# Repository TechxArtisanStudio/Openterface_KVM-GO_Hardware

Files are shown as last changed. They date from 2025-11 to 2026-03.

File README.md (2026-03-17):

# Welcome to Openterface_KVM-GO_Hardware
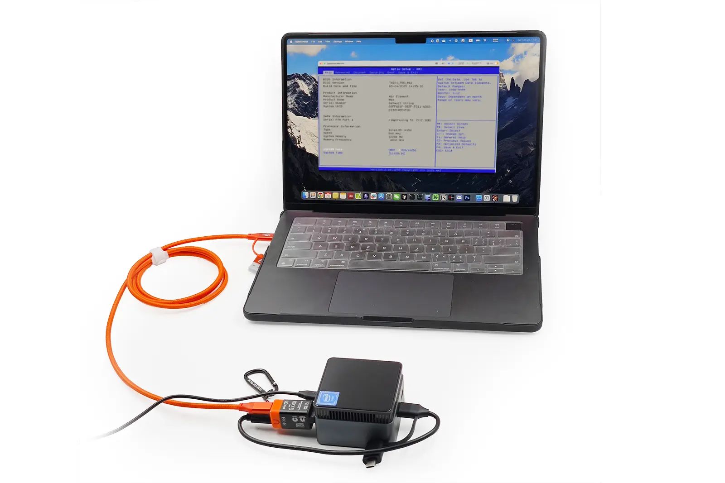
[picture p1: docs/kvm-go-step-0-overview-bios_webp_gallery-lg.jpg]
use-case-pc-angled-view


## Overview

The [Openterface KVM-GO](https://openterface.com/product/kvm-go/) is a compact and portable open-source KVM-over-USB gadget designed to provide convenient access to headless devices. It allows users to use their laptop, tablet, or smartphone to display and control a target machine through a direct USB connection.

The KVM-GO series includes three hardware variants, designed for different video interfaces:

- KVM-GO HDMI  
- KVM-GO DP  
- KVM-GO VGA  

Each variant integrates a video capture interface and keyboard/mouse emulation into a single compact device. By connecting the device to the target machine’s video output and USB port, users can view the screen and control the system from a host device without requiring network connectivity.

This solution is particularly useful for developers, IT professionals, and hardware enthusiasts who frequently work with servers, embedded systems, or other headless devices.

## Hardware Features

The Openterface KVM-GO PCB board comes with a variety of features designed to provide a seamless and efficient user experience:

- Compact Design: Small and portable form factor suitable for mobile troubleshooting setups.  
- Multiple Video Variants: Available in HDMI, DP, and VGA versions to support different target devices.  
- Direct Plug-in Video Interface: Built-in connector allows direct connection to the target system.  
- USB Connectivity: Simulates keyboard and mouse inputs through a USB connection.  
- Open Source: Fully open-source hardware and software, allowing community-driven development and customization.  
- High Compatibility: Supports a wide range of devices and operating systems.  
- Easy Setup: Plug-and-play functionality with minimal configuration required.  
- [Community Support](https://openterface.com/about/community/): Backed by an active open-source community.
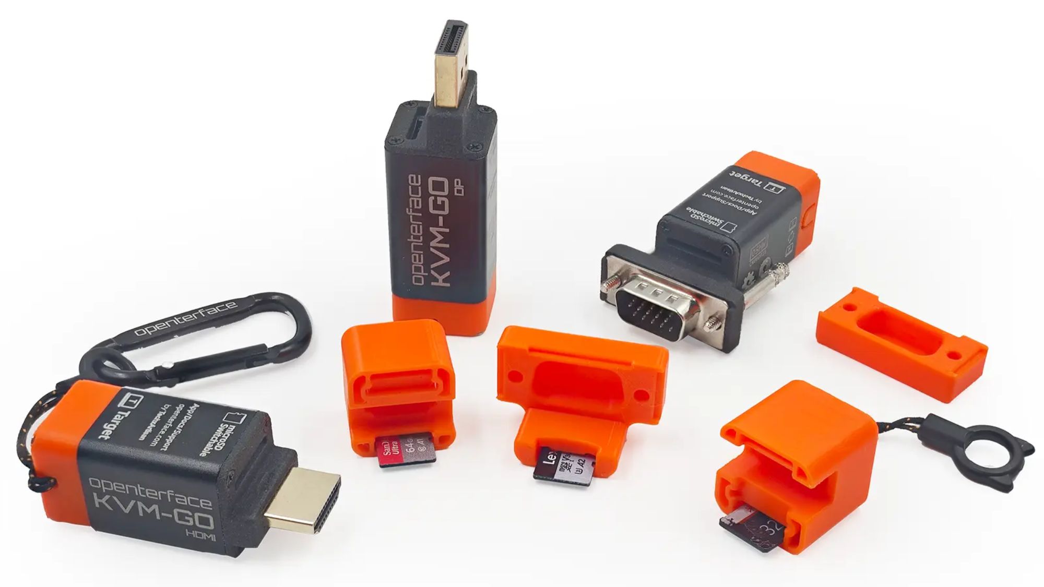
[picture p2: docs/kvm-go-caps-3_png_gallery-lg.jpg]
KVM-GO series
  

## Firmware

KVM-GO works with [Openterface_KM](https://github.com/TechxArtisanStudio/Openterface_KM), the keyboard and mouse emulation firmware used for target-side HID control in the Openterface KVM ecosystem.

## Software

To use the KVM-GO device, the host device must install an Openterface host application.

Supported platforms include:

- [Windows](https://github.com/TechxArtisanStudio/Openterface_QT)
- [Mac](https://github.com/TechxArtisanStudio/Openterface_MacOS)
- [Linux](https://github.com/TechxArtisanStudio/Openterface_QT)  
- [Android](https://github.com/TechxArtisanStudio/Openterface_Android)
- iPadOS  
- [Web browser applications](https://openterface-viewer.pages.dev/)  

The host application allows users to view the captured video stream and control the target device using keyboard and mouse input.

No software installation is required on the target device. Simply connect a device with a video output and a USB port for keyboard and mouse control.

## PCB Design
_cgi-bin_mmwebwx-bin_webwxgetmsgimg__ MsgID=7964427320763733275 skey=@crypt_1f07134c_f258b5d86cb3b41255d6e1a63a1030d6 mmweb_appid=wx_webfilehelper

## license

- Hardware is released under CERN Open Hardware Licence Version 2 - Strongly Reciprocal  
- Its softwares are released under GNU AFFERO GENERAL PUBLIC LICENSE Version 3  
- Documentation is released under [CC BY-SA 4.0](https://creativecommons.org/licenses/by-sa/4.0/legalcode)

## Get Involved

Interested in contributing to the project? We welcome community involvement and contributions. For more information about getting involved, please visit our community pages or contact us directly.

KVM-GO-bundle-hook-bag

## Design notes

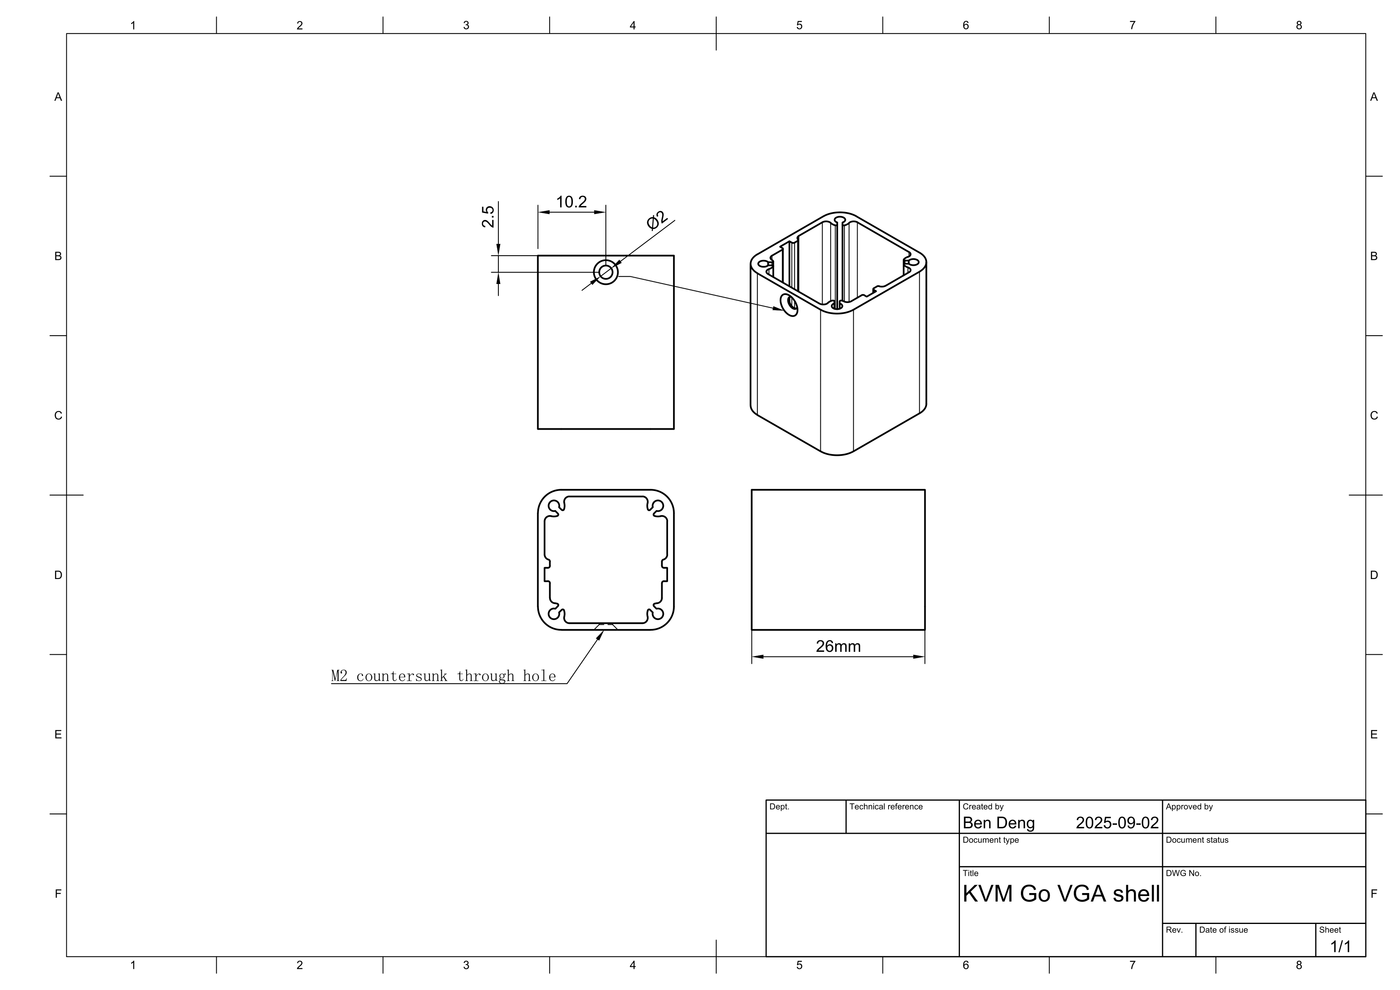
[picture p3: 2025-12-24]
models/VGA/KVM_Go_VGA.png

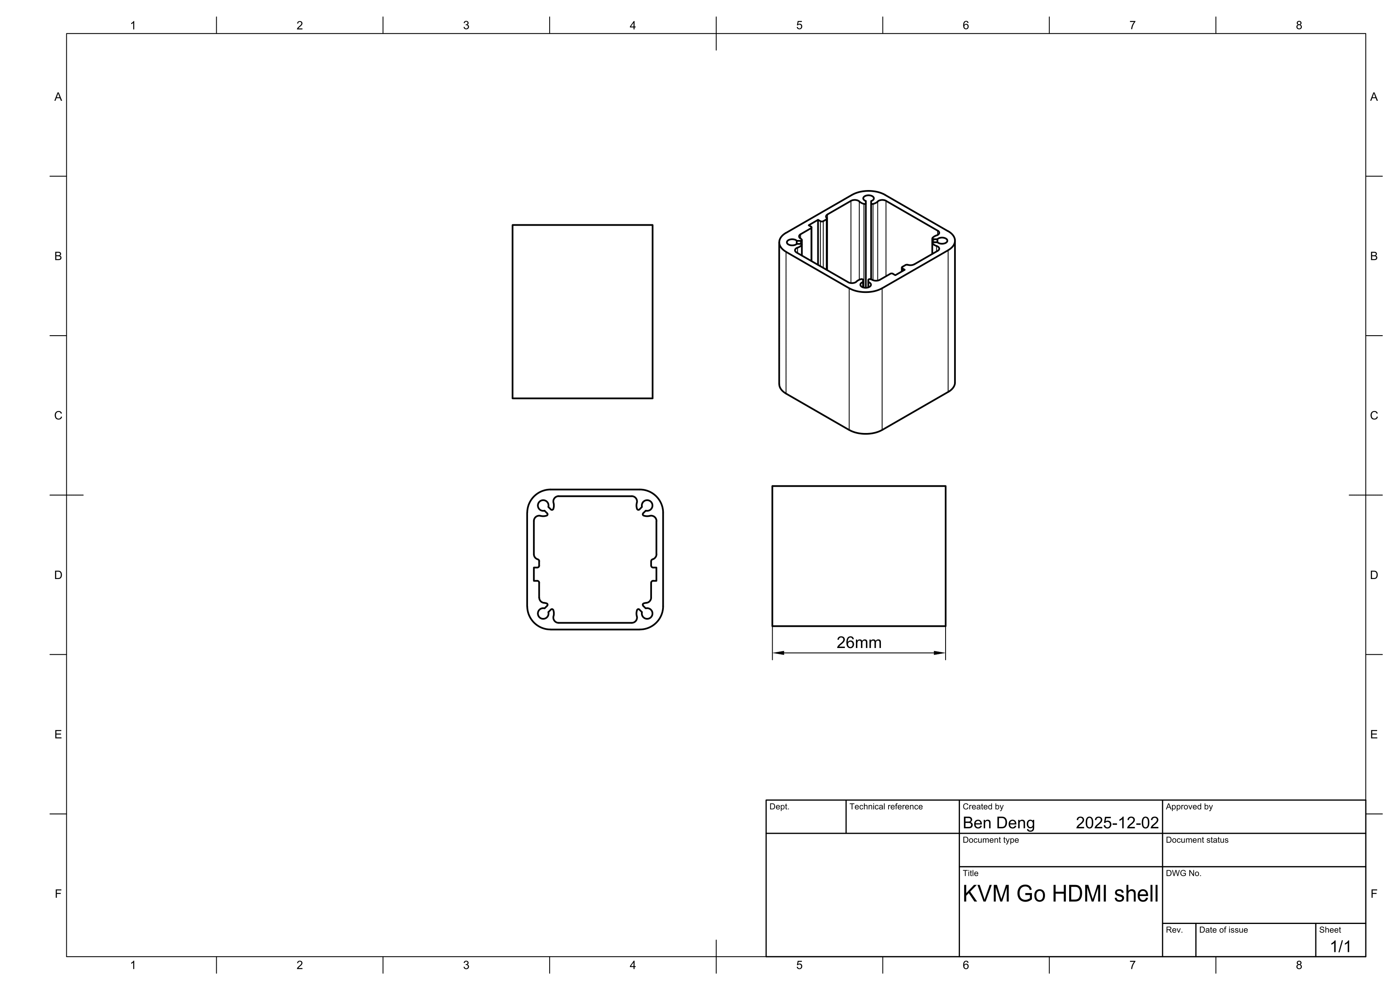
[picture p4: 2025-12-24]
models/HDMI/KVM_Go_HDMI.png

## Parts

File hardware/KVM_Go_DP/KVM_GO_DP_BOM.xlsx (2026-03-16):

No. | Quantity | Comment | Designator | Footprint | Value | Manufacturer Part | Manufacturer | Supplier Part | Supplier
1 | 7 | 10uF | C1,C2,C3,C7,C17,C30,C35 | C0402 | 10uF | HGC0402R5106M100NTEJ | Chinocera(华瓷) | C7472949 | LCSC
2 | 27 | 100nF | C4,C5,C6,C8,C10,C13,C14,C18,C19,C20,C21,C22,C23,C24,C25,C28,C29,C31,C32,C33,C34,C36,C37,C38,C39,C40,C41 | C0402 | 100nF | CL05B104KO5NNNC | SAMSUNG(三星) | C1525 | LCSC
3 | 4 | 100nF | C9,C12,C26,C27 | C0201 | 100nF | CGA0201X5R104K100ET | HRE(芯声) | C6119757 | LCSC
4 | 2 | 18pF | C11,C15 | C0402 | 18pF | CC0402FRNPO9BN180 | YAGEO(国巨) | C541431 | LCSC
5 | 1 | 1uF | C16 | C0402 | 1uF | CL05A105KA5NQNC | SAMSUNG(三星) | C52923 | LCSC
6 | 1 | 10uF | C42 | C0603 | 10uF | CGA0603X5R106K100JT | HRE(芯声) | C6119842 | LCSC
7 | 1 | DISPLAYPORT_公_夹板 | CN1 | DISPLAYPORT_公_夹板
8 | 1 | PRTR5V0U2X | D11 | SOT-143-4_L2.9-W1.3-P1.92-LS2.4-BL |  | PRTR5V0U2X | TECH PUBLIC(台舟) | C2827688 | LCSC
9 | 2 | RClamp0524PATCT | D12,D13 | SLP2510P8_L2.5-W1.0-P0.50-BL |  | RClamp0524PATCT | SEMTECH | C40960 | LCSC
10 | 4 | MPZ1608S600ATDH5 | FB1,FB2,FB3,FB4 | L0603 |  | MPZ1608S600ATDH5 | TDK | C307775 | LCSC
11 | 2 | 5AKL3-8840-103-W0 | H1,H2 | HDR-TH_3P-P2.00-V-M |  | 5AKL3-8840-103-W0 | SAMZO(三佐) | C29780895 | LCSC
12 | 2 | 2.2uH | L1,L2 | IND-SMD_L2.0-W1.6-B | 2.2uH | FWP201610P-2R2ML | cjiang(长江微电) | C5179461 | LCSC
13 | 1 | 2.2uH | L4 | L0603 | 2.2uH | CMH160808B2R2MT | FH(风华) | C394950 | LCSC
14 | 1 | 4.7kΩ | R1 | R0402 | 4.7kΩ | 0402WGF4701TCE | UNI-ROYAL(厚声) | C25900 | LCSC
15 | 1 | 41.2kΩ | R2 | R0402 | 41.2kΩ | FRC0402F4122TS | FOJAN(富捷) | C2998053 | LCSC
16 | 4 | 1MΩ | R3,R4,R9,R10 | R0402 | 1MΩ | 0402WGF1004TCE | UNI-ROYAL(厚声) | C26083 | LCSC
17 | 2 | 150kΩ | R5,R19 | R0402 | 150kΩ | FRC0402F1503TS | FOJAN(富捷) | C2909320 | LCSC
18 | 4 | 10kΩ | R6,R7,R14,R22 | R0402 | 10kΩ | 0402WGF1002TCE | UNI-ROYAL(厚声) | C25744 | LCSC
19 | 1 | 220kΩ | R8 | R0402 | 220kΩ | 0402WGF2203TCE | UNI-ROYAL(厚声) | C25767 | LCSC
20 | 1 | 200Ω | R11 | R0402 | 200Ω | 0402WGF2000TCE | UNI-ROYAL(厚声) | C25087 | LCSC
21 | 1 | 47kΩ | R12 | R0402 | 47kΩ | 0402WGF4702TCE | UNI-ROYAL(厚声) | C25792 | LCSC
22 | 1 | 10.5kΩ | R13 | R0402 | 10.5kΩ | 0402WGF1052TCE | UNI-ROYAL(厚声) | C25850 | LCSC
23 | 1 | 22kΩ | R15 | R0402 | 22kΩ | 0402WGF2202TCE | UNI-ROYAL(厚声) | C25768 | LCSC
24 | 1 | 1.6kΩ | R16 | R0402 | 1.6kΩ | 0402WGF1601TCE | UNI-ROYAL(厚声) | C4908 | LCSC
25 | 1 | 0Ω | R17 | R0402 | 0Ω | 0402WGF0000TCE | UNI-ROYAL(厚声) | C17168 | LCSC
26 | 1 | 680kΩ | R18 | R0402 | 680kΩ | RC0402FR-07680KL | YAGEO(国巨) | C163456 | LCSC
27 | 2 | 1kΩ | R20,R21 | R0402 | 1kΩ | 0402WGF1001TCE | UNI-ROYAL(厚声) | C11702 | LCSC
28 | 1 | 124kΩ | R23 | R0402 | 124kΩ | FRC0402F1243TS | FOJAN(富捷) | C2933070 | LCSC
29 | 1 | IT6563FN | U2 | QFN-56_L7.0-W7.0-P0.40-BL-EP5.2
30 | 1 | MS2130S | U3 | QFN-64_L9.0-W9.0-P0.50-BL-EP4.8
31 | 2 | BLM18PG121SN1D | U5,U7 | L0603 |  | BLM18PG121SN1D | muRata(村田) | C14709 | LCSC
32 | 1 | TPRT9193-25GB | U8 | SOT-23-5_L2.9-W1.6-P0.95-LS2.8-BL |  | TPRT9193-25GB | TECH PUBLIC(台舟) | C2827655 | LCSC
33 | 1 | W25Q16JVUXIQ | U9 | USON-8_L3.0-W2.0-P0.50-BL-EP |  | W25Q16JVUXIQ | Winbond(华邦) | C2843335 | LCSC
34 | 1 | CH213K | U10 | SOT-23-3_L2.9-W1.6-P1.90-LS2.8-BR |  | CH213K | WCH(南京沁恒) | C5456874 | LCSC
35 | 1 | VL162 | U11 | MQFN-28_L4.5-W3.5-P0.40-BL-EP |  | VL162 | VIA Labs(威锋电子) | C19270896 | LCSC
36 | 3 | TLV62569DBVR | U29,U30,U31 | SOT-23-5_L3.0-W1.7-P0.95-LS2.8-BR |  | TLV62569DBVR | TI(德州仪器) | C141836 | LCSC
37 | 1 | 918-418K2029F30000 | USB1 | USB-C-SMD_918-418K2029F30000 |  | 918-418K2029F30000 | 精拓金 | C709039 | LCSC
38 | 1 | 27MHz | X1 | CRYSTAL-SMD_4P-L3.2-W2.5-BL-1 | 27MHz | X322527MSB4SI | YXC(扬兴晶振) | C9008 | LCSC
39 | 1 | 24MHz | X2 | CRYSTAL-SMD_4P-L3.2-W2.5-BL | 24MHz | X322524MOB4SI | YXC(扬兴晶振) | C70590 | LCSC

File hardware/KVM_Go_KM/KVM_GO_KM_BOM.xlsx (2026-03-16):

No. | Quantity | Comment | Designator | Footprint | Value | Manufacturer Part | Manufacturer | Supplier Part | Supplier
1 | 3 | 1uF | C1,C2,C3 | C0402 | 1uF | CL05A105KA5NQNC | SAMSUNG(三星) | C52923 | LCSC
2 | 2 | 12pF | C4,C5 | C0402 | 12pF | GCM1555C1H120FA16D | muRata(村田) | C393682 | LCSC
3 | 1 | 22nF | C6 | C0402 | 22nF | CL05B223KB5NNNC | SAMSUNG(三星) | C337699 | LCSC
4 | 14 | 100nF | C7,C8,C9,C10,C12,C13,C14,C15,C16,C17,C18,C19,C20,C21 | C0402 | 100nF | CL05B104KO5NNNC | SAMSUNG(三星) | C1525 | LCSC
5 | 1 | 10uF | C11 | C0402 | 10uF | HGC0402R5106M100NTEJ | Chinocera(华瓷) | C7472949 | LCSC
6 | 1 | TF PUSH | CARD1 | TF-SMD_TF-PUSH |  | TF PUSH | SHOU HAN(首韩) | C393941 | LCSC
7 | 2 | 5AKL3-8840-103-W0 | H1,H2 | HDR-TH_3P-P2.00-V-M_5 |  | 5AKL3-8840-103-W0 | SAMZO(三佐) | C29780895 | LCSC
8 | 2 | SL2.1s | HUB1,HUB2 | SSOP-16_L4.6-W2.6-P0.53-LS4.0-BL |  | SL2.1s | CoreChips(和芯润德) | C2684433 | LCSC
9 | 1 | 1.5nH | L1 | L0402 | 1.5nH | LQG15HS1N5S02D | muRata(村田) | C77106 | LCSC
10 | 1 | 2nH | L2 | L0402 | 2nH | LQG15HS2N0S02D | muRata(村田) | C18216 | LCSC
11 | 1 | FM-3510RGBA-SG | LED1 | LED-SMD_FM-3510RGBA-SG |  | FM-3510RGBA-SG | 国星光电 | C727903 | LCSC
12 | 1 | 0Ω | R1 | R0402 | 0Ω | 0402WGF0000TCE | UNI-ROYAL(厚声) | C17168 | LCSC
13 | 3 | 10kΩ | R2,R4,R5 | R0402 | 10kΩ | 0402WGF1002TCE | UNI-ROYAL(厚声) | C25744 | LCSC
14 | 2 | 5.1kΩ | R3,R6 | R0402 | 5.1kΩ | 0402WGF5101TCE | UNI-ROYAL(厚声) | C25905 | LCSC
15 | 2 | 4.7kΩ | R8,R9 | R0402 | 4.7kΩ | 0402WGF4701TCE | UNI-ROYAL(厚声) | C25900 | LCSC
16 | 1 | 10kΩ | R10 | R0201 | 10kΩ | 0201WMF1002TEE | UNI-ROYAL(厚声) | C473048 | LCSC
17 | 1 | TS-1133-C-A | SW1 | SW-SMD_TS-1133-C-A |  | TS-1133-C-A | XKB Connectivity(中国星坤) | C561509 | LCSC
18 | 1 | CH32V208GBU6 | U1 | QFN-28_L4.0-W4.0-P0.40-BL-EP2.8 |  | CH32V208GBU6 | WCH(南京沁恒) | C7434833 | LCSC
19 | 1 | ADWH002 | U2 | ANT-SMD_L5.0-W2.0_HM5B |  | ADWH002 | MyAntenna(摩天射频) | C22467691 | LCSC
20 | 1 | RT9193-33GB | U3 | SOT-23-5_L3.0-W1.7-P0.95-LS2.8-BL |  | RT9193-33GB | RICHTEK(立锜) | C15651 | LCSC
21 | 1 | GL823K-HCY04 | U4 | SSOP-16_L4.9-W3.9-P0.64-LS6.0-BL |  | GL823K-HCY04 | GENESYS(创惟) | C284879 | LCSC
22 | 1 | FSUSB42MUX | U5 | MSOP-10_L3.0-W3.0-P0.50-LS5.0-BL |  | FSUSB42MUX | onsemi(安森美) | C11355 | LCSC
23 | 1 | SY6280AAC | U6 | SOT-23-5_L3.0-W1.7-P0.95-LS2.8-BL |  | SY6280AAC | silergy(矽力杰) | C55136 | LCSC
24 | 1 | CH213K | U7 | SOT-23-3_L2.9-W1.6-P1.90-LS2.8-BR |  | CH213K | WCH(南京沁恒) | C5456874 | LCSC
25 | 1 | DS18B20U(UMW) | U8 | MSOP-8_L3.0-W3.0-P0.65-LS4.9-BL |  | DS18B20U(UMW) | UMW(友台半导体) | C695836 | LCSC
26 | 1 | TYPEC-304-ACP16 | USB1 | USB-C-SMD_TYPE-C-16P-1 |  | TYPEC-304-ACP16 | XUNPU(讯普) | C2982555 | LCSC
27 | 1 | 32.768kHz | X1 | CRYSTAL-SMD_2P-L2.0-W1.2 | 32.768kHz | XKHEL89CGI-112YLC-32.768K | YXC(扬兴晶振) | C7500573 | LCSC
28 | 1 | 32MHz | X2 | CRYSTAL-SMD_4P-L3.2-W2.5-BL | 32MHz | X322532MOB4SI | YXC(扬兴晶振) | C9009 | LCSC
29 | 2 | 12MHz | X3,X4 | CRYSTAL-SMD_4P-L2.5-W2.0-BL-A | 12MHz | 2TJ412000HYGBC | JYJE(晶友嘉) | C2149204 | LCSC

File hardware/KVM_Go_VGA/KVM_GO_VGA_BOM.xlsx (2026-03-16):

No. | Quantity | Comment | Designator | Footprint | Value | Manufacturer Part | Manufacturer | Supplier Part | Supplier
1 | 3 | 47nF | C2,C3,C4 | C0402 | 47nF | CC0402KRX7R9BB473 | YAGEO(国巨) | C272875 | LCSC
2 | 10 | 100nF | C5,C43,C45,C76,C77,C80,C83,C85,C87,C93 | C0402 | 100nF | CL05B104KO5NNNC | SAMSUNG(三星) | C1525 | LCSC
3 | 2 | 22pF | C41,C42 | C0402 | 22pF | 0402CG220J500NT | FH(风华) | C1555 | LCSC
4 | 12 | 10uF | C56,C69,C72,C74,C75,C78,C79,C88,C89,C90,C91,C92 | C0402 | 10uF | HGC0402R5106M100NTEJ | Chinocera(华瓷) | C7472949 | LCSC
5 | 3 | 4.7uF | C60,C61,C66 | C0402 | 4.7uF | CL05A475KP5NRNC | SAMSUNG(三星) | C368809 | LCSC
6 | 2 | 10uF | C81,C82 | C0603 | 10uF | CGA0603X5R106K100JT | HRE(芯声) | C6119842 | LCSC
7 | 1 | PRTR5V0U2X | D11 | SOT-143-4_L2.9-W1.3-P1.92-LS2.4-BL |  | PRTR5V0U2X | TECH PUBLIC(台舟) | C2827688 | LCSC
8 | 1 | RClamp0524PATCT | D14 | SLP2510P8_L2.5-W1.0-P0.50-BL |  | RClamp0524PATCT | SEMTECH | C40960 | LCSC
9 | 2 | 5AKL3-8840-103-W0 | H1,H2 | HDR-TH_3P-P2.00-V-M_5 |  | 5AKL3-8840-103-W0 | SAMZO(三佐) | C29780895 | LCSC
10 | 3 | 2.2uH | L6,L7,L8 | IND-SMD_L2.0-W1.6-B | 2.2uH | FWP201610P-2R2ML | cjiang(长江微电) | C5179461 | LCSC
11 | 4 | 4.7kΩ | R1,R6,R7,R9 | R0402 | 4.7kΩ | 0402WGF4701TCE | UNI-ROYAL(厚声) | C25900 | LCSC
12 | 3 | 1kΩ | R2,R40,R45 | R0402 | 1kΩ | 0402WGF1001TCE | UNI-ROYAL(厚声) | C11702 | LCSC
13 | 2 | 1MΩ | R3,R4 | R0402 | 1MΩ | 0402WGF1004TCE | UNI-ROYAL(厚声) | C26083 | LCSC
14 | 2 | 5.1kΩ | R11,R46 | R0402 | 5.1kΩ | 0402WGF5101TCE | UNI-ROYAL(厚声) | C25905 | LCSC
15 | 3 | 75Ω | R14,R18,R19 | R0402 | 75Ω | 0402WGF750JTCE | UNI-ROYAL(厚声) | C25133 | LCSC
16 | 1 | NC | R32 | R0402 | NC | 0402WGF0000TCE | UNI-ROYAL(厚声) |  | LCSC
17 | 1 | 680kΩ | R57 | R0402 | 680kΩ | RC0402FR-07680KL | YAGEO(国巨) | C163456 | LCSC
18 | 4 | 150kΩ | R58,R59,R60,R61 | R0402 | 150kΩ | FRC0402F1503TS | FOJAN(富捷) | C2909320 | LCSC
19 | 1 | 300kΩ | R62 | R0402 | 300kΩ | 0402WGF3003TCE | UNI-ROYAL(厚声) | C25774 | LCSC
20 | 2 | 100Ω | R63,R64 | R0402 | 100Ω | 0402WGF1000TCE | UNI-ROYAL(厚声) | C25076 | LCSC
21 | 1 | CH213K | U1 | SOT-23-3_L2.9-W1.6-P1.90-LS2.8-BR |  | CH213K |  | C5456874 | LCSC
22 | 1 | MS2109S | U4 | QFN-48_L7.0-W7.0-P0.50-TL-EP4.1
23 | 3 | BLM18PG121SN1D | U17,U30,U31 | L0603 |  | BLM18PG121SN1D | muRata(村田) | C14709 | LCSC
24 | 1 | MS9288C | U23 | QFN-48_L6.0-W6.0-P0.40-TL-EP4.2 |  | MS9288C | Macrosilicon(宏晶微) | C2914316 | LCSC
25 | 1 | AT24C16M5/TR | U26 | SOT-23-5_L2.9-W1.6-P0.95-LS2.8-BR |  | AT24C16M5/TR | HGSEMI(华冠) | C7432356 | LCSC
26 | 3 | TLV62569DBVR | U27,U28,U29 | SOT-23-5_L3.0-W1.7-P0.95-LS2.8-BR |  | TLV62569DBVR | TI(德州仪器) | C141836 | LCSC
27 | 1 | 918-418K2029F30000 | USB5 | USB-C-SMD_918-418K2029F30000 |  | 918-418K2029F30000 | 精拓金 |  | LCSC
28 | 1 | VGA15P | VGA1 | 夹板vga
29 | 1 | 24MHz | X1 | CRYSTAL-SMD_4P-L3.2-W2.5-BL | 24MHz | X322524MOB4SI | YXC(扬兴晶振) | C70590 | LCSC
30 | 1 | 24.576MHz | X3 | CRYSTAL-SMD_4P-L2.5-W2.0-BL | 24.576MHz | SX2B24.576F1010F30 | SCTF(星通时频) | C7301978 | LCSC

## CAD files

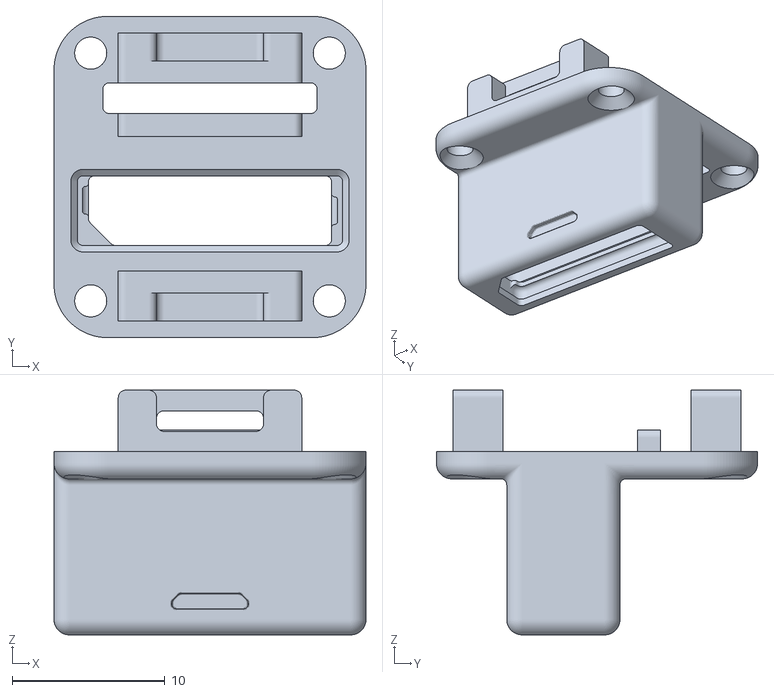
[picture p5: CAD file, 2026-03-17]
models/DP/DP_Cap.stl
20.4 x 21.0 x 16.0

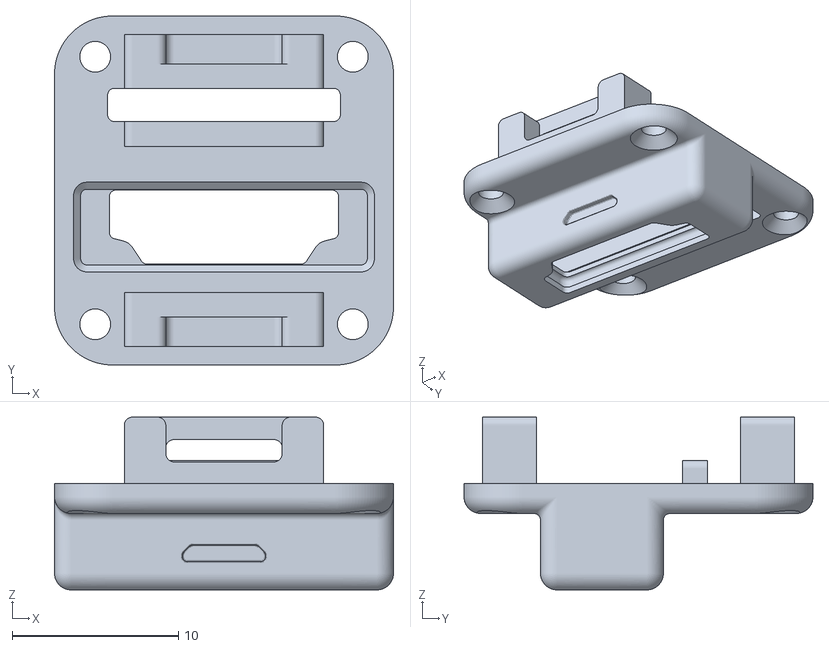
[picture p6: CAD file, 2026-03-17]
models/HDMI/HDMI_Cap.stl
20.4 x 21.0 x 10.4

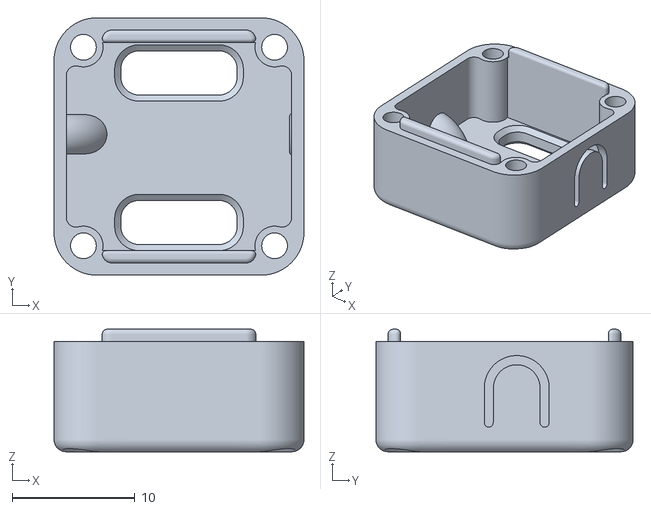
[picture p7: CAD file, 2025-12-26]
models/TypeC_Cap/TypeC_Cap_RGB.stl
20.4 x 21.0 x 10.0

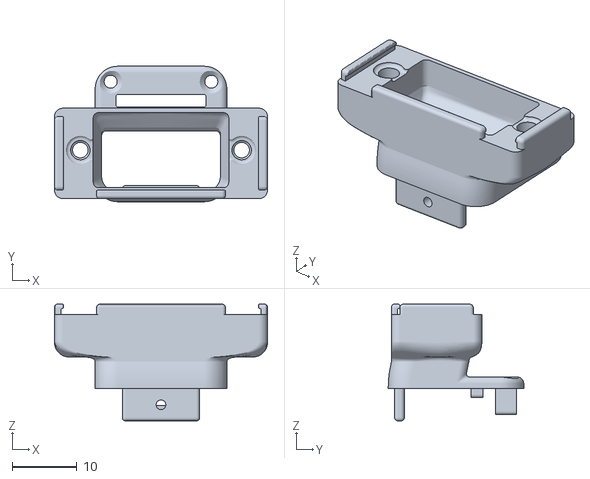
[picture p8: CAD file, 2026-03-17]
models/VGA/VGA_Cap.stl
33.0 x 21.0 x 18.1

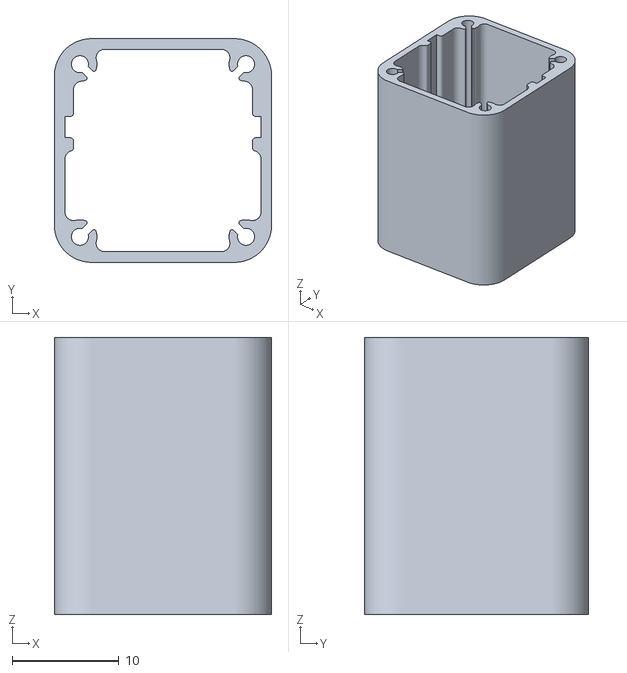
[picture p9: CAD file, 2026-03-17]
models/DP/DP_aluminum_shell.stl
20.4 x 21.0 x 26.0

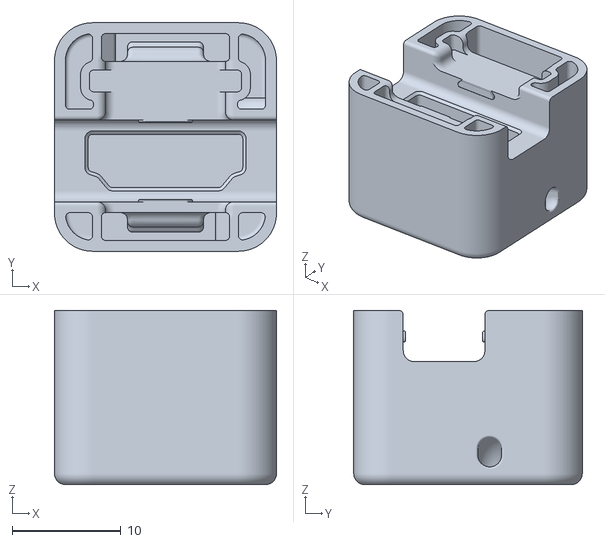
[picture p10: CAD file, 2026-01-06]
models/HDMI/KVM_Go_HDMICaps_WithSDCardSlot and key hole.stl
20.4 x 21.0 x 16.0

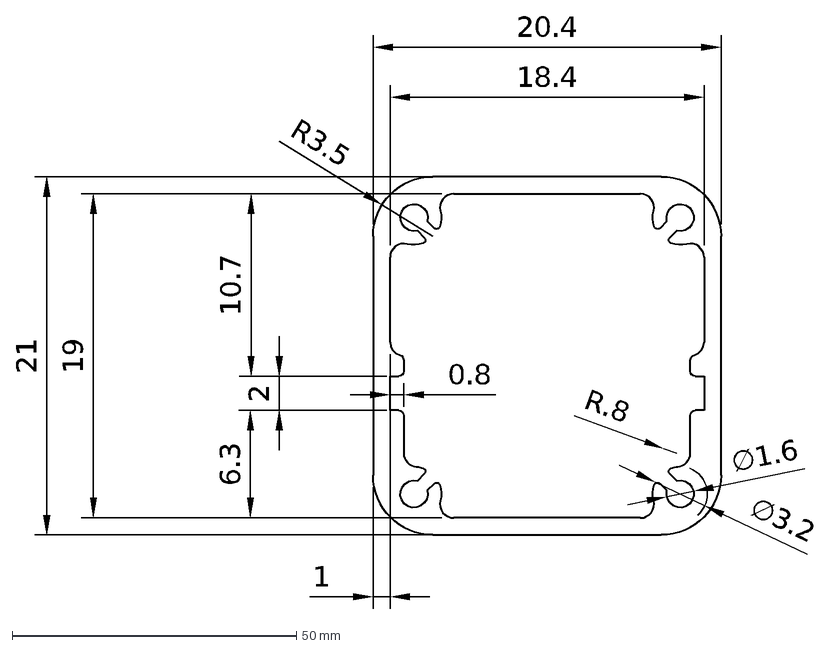
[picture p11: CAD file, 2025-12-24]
models/TypeC_Cap/KVM_Go_shell.dxf
21
20.4
R3.5
1
18.4
19
0.8
6.3
10.7
2
R.8
∅1.6
∅3.2

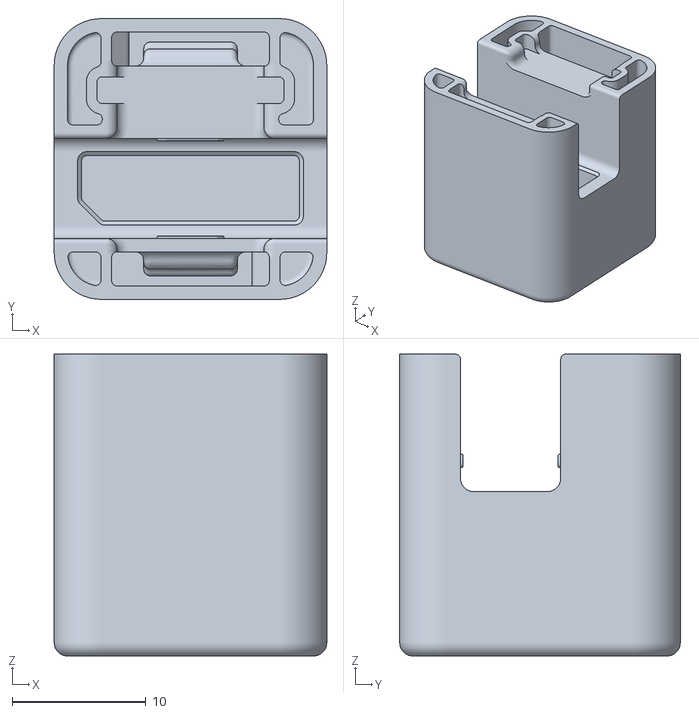
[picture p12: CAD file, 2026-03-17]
models/DP/KVM_Go_DPCaps_WithSDCardSlot.stl
20.4 x 21.0 x 22.6

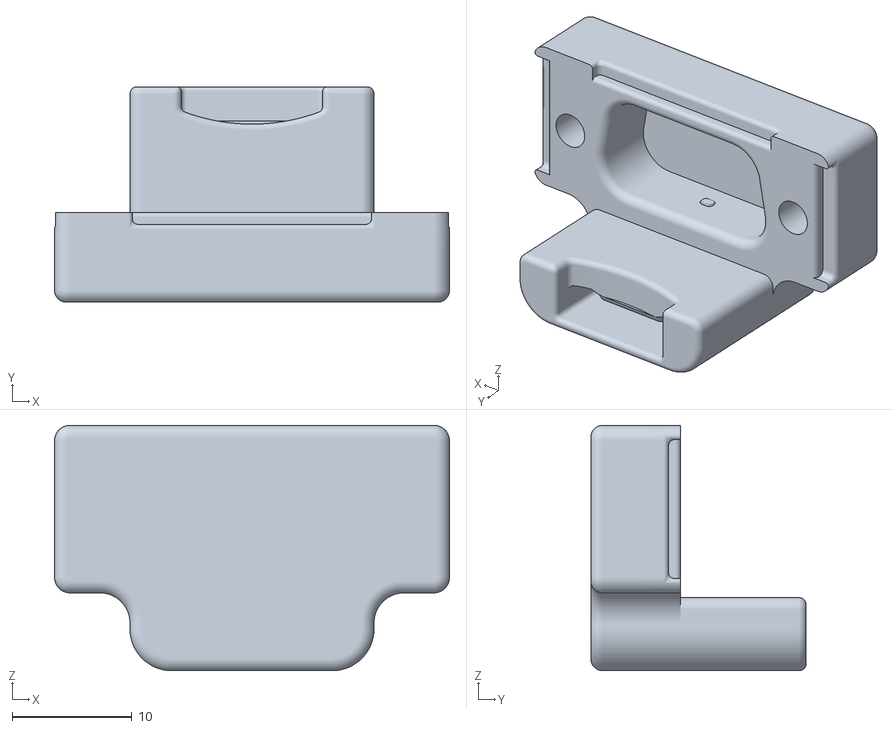
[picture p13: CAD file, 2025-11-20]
models/VGA/KVM_Go_VGACaps_WithSDCardSlot.stl
33.0 x 18.0 x 20.5

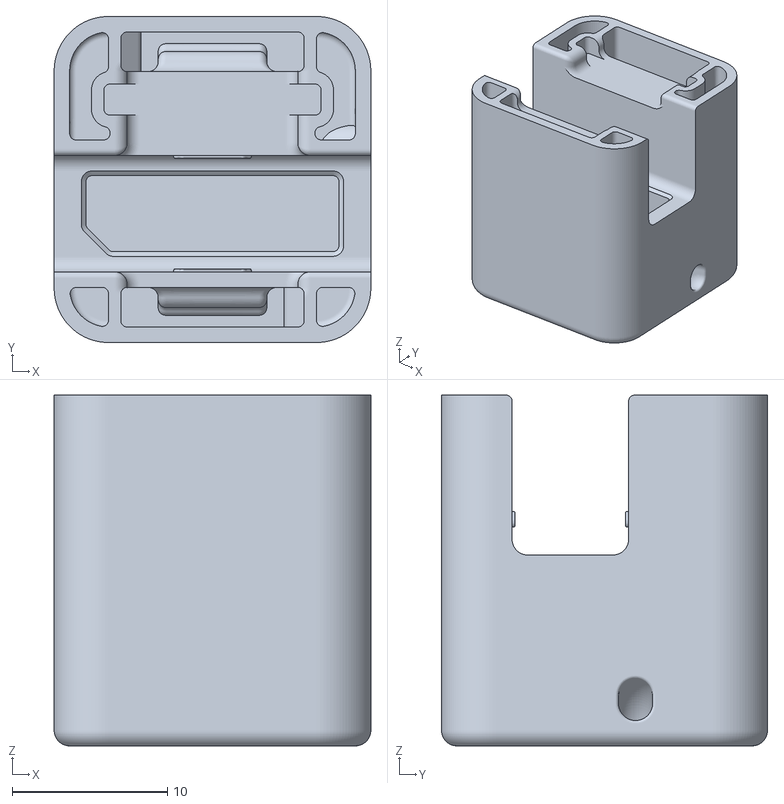
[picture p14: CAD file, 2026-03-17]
models/DP/KVM_Go_DPCaps_WithSDCardSlot and key hole.stl
20.4 x 21.0 x 22.6

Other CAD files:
hardware/KVM_Go_HDMI/KVM_GO_HDMI.step
hardware/KVM_Go_VGA/KVM_GO_VGA.step
models/VGA/VGA_aluminum_shell.stl
models/HDMI/KVM_Go_HDMICaps_WithSDCardSlot.stl
models/HDMI/HDM_aluminum_shell.stl
models/VGA/KVM_Go_VGACaps_WithSDCardSlot and key hole.stl

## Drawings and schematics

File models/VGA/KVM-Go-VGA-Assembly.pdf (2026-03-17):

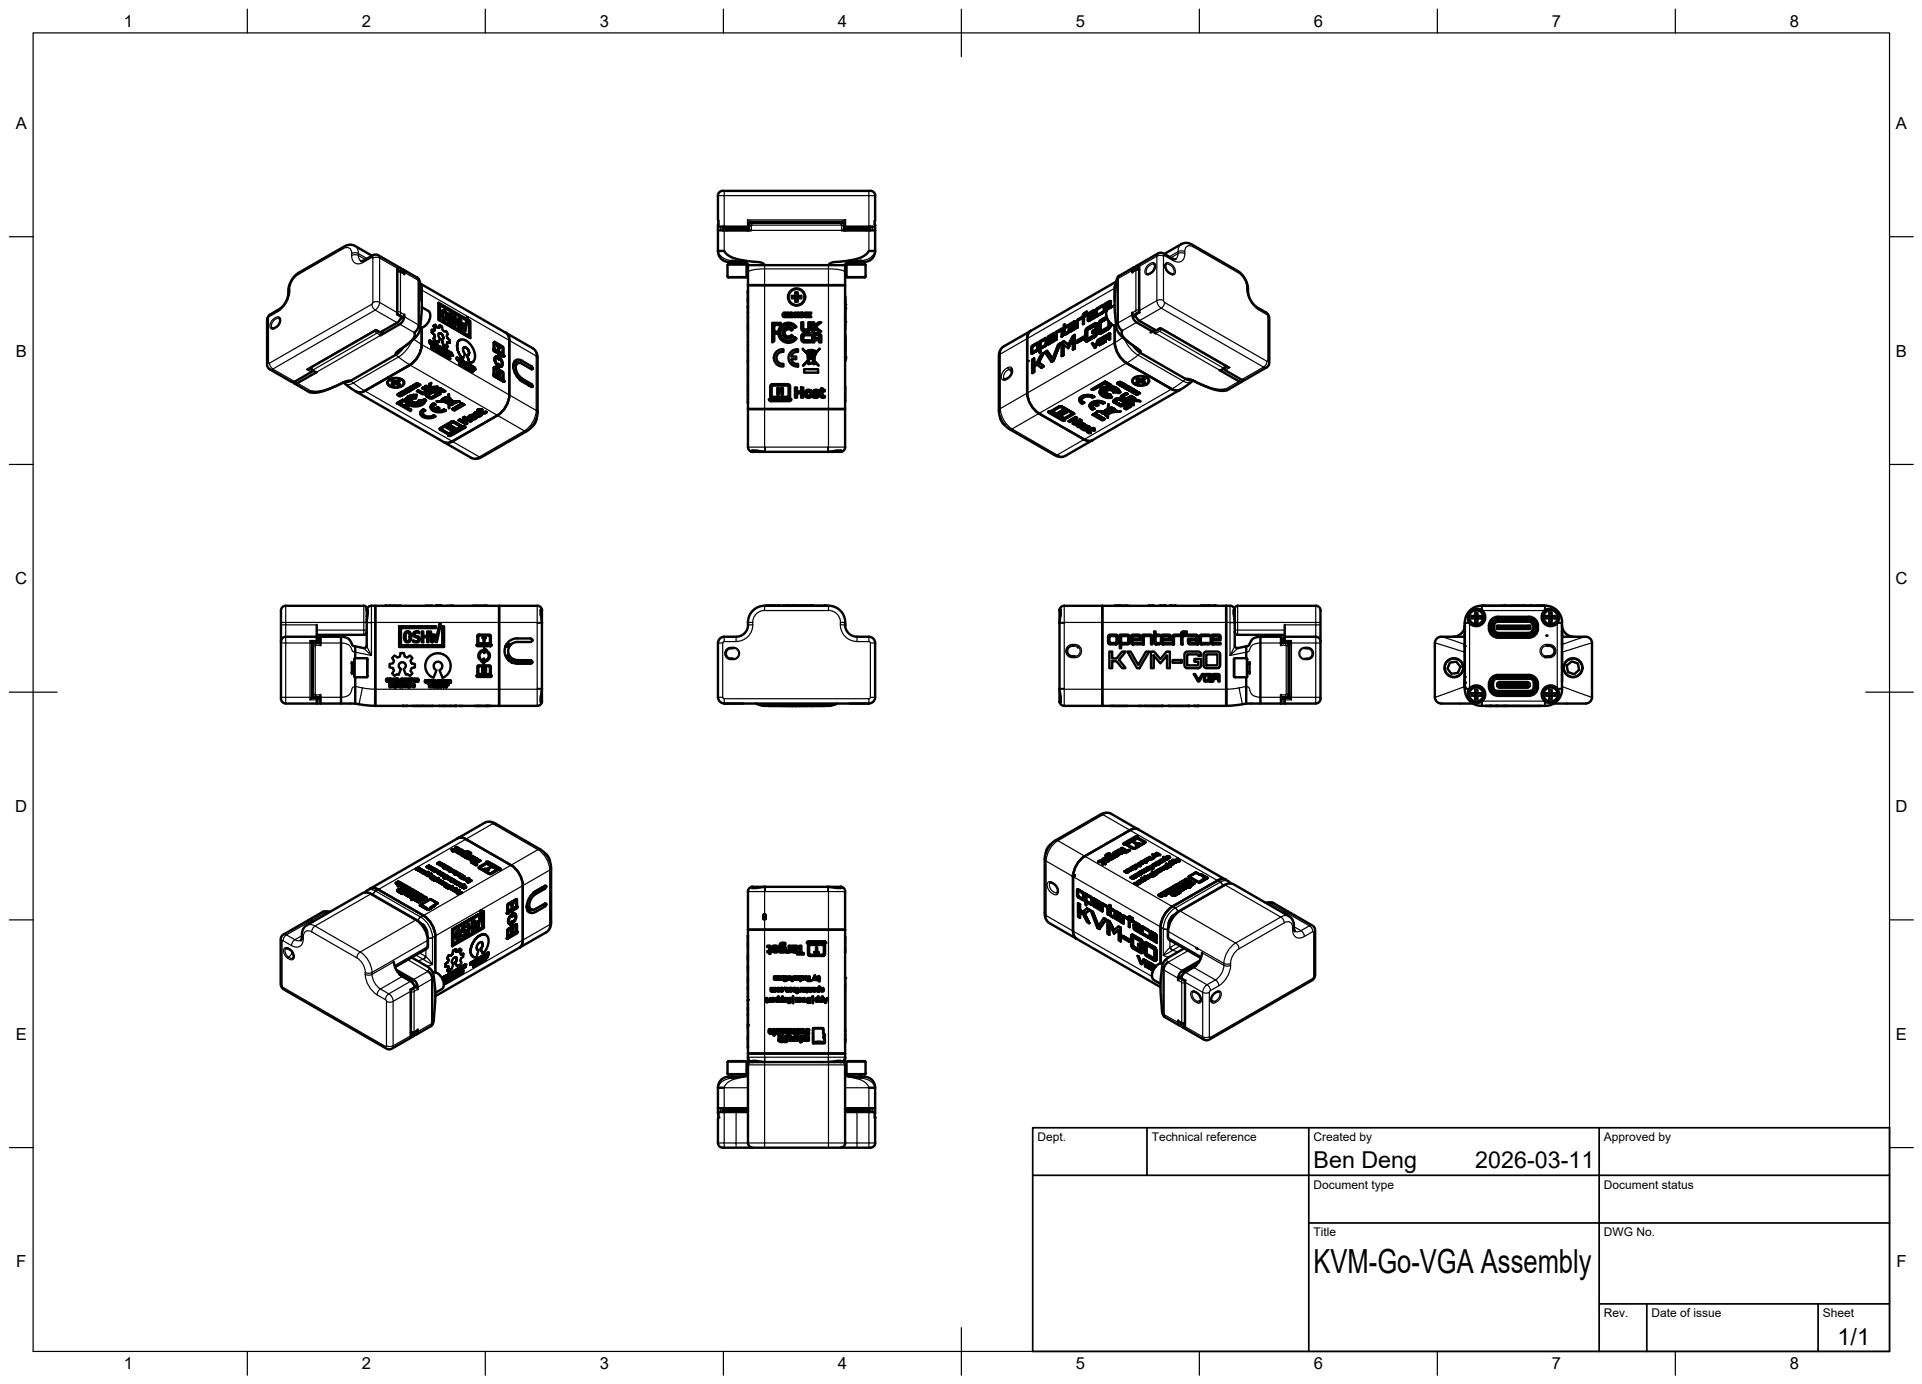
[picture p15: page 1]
Dept.; Technical reference; Created by; Approved by; Document type; Document status; Title; DWG No.; Rev.; Date of issue; Sheet; Ben Deng

KVM-Go-VGA Assembly

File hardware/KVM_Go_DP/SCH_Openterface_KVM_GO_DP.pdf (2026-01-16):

5V-1.1V

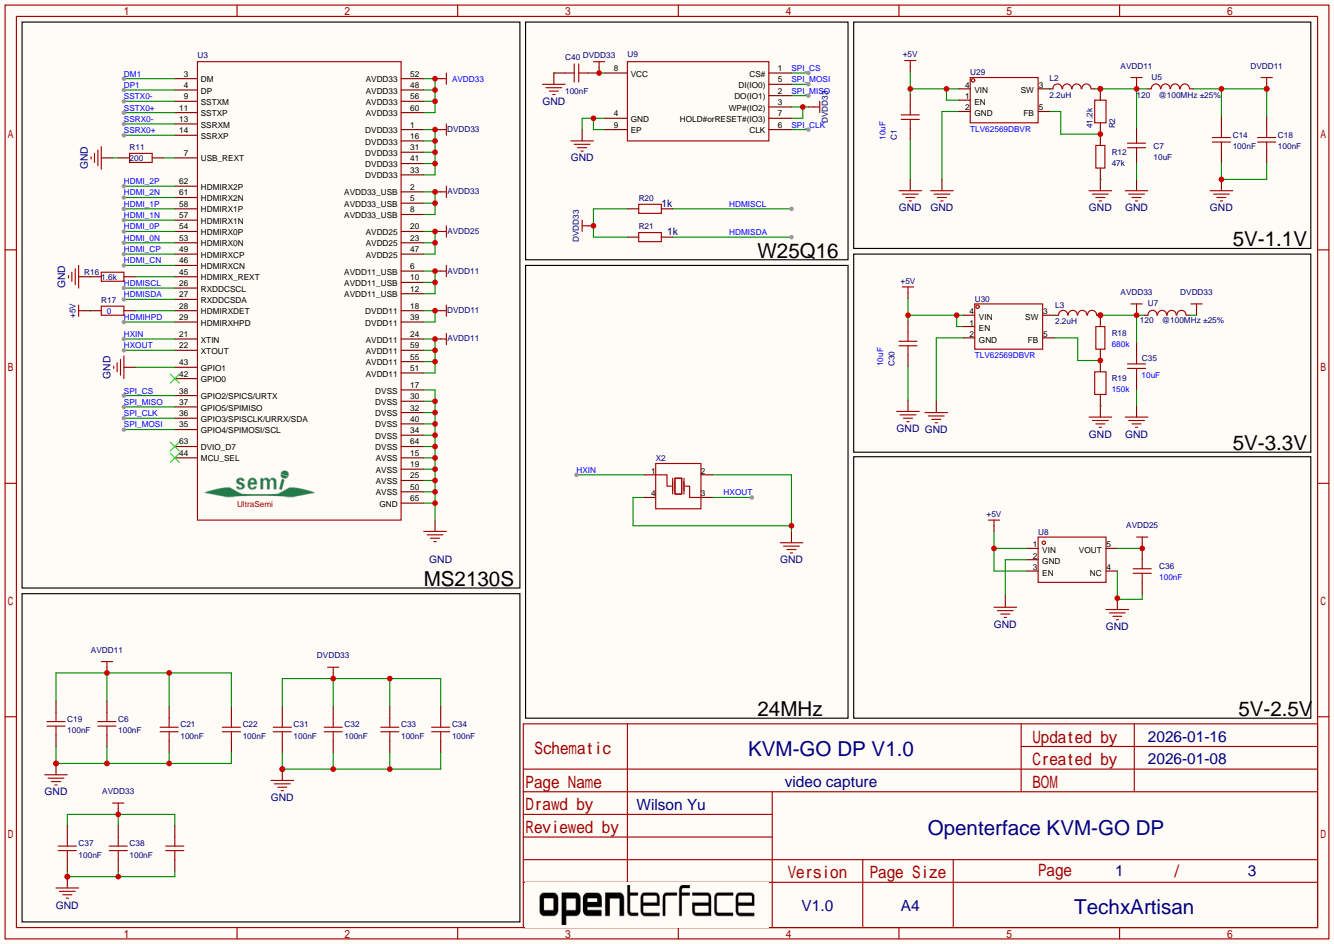
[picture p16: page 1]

HDMIRXHPD 29 HDMIRXDET 28 RXDDCSDA 27 RXDDCSCL 26

Openterface KVM-GO DP

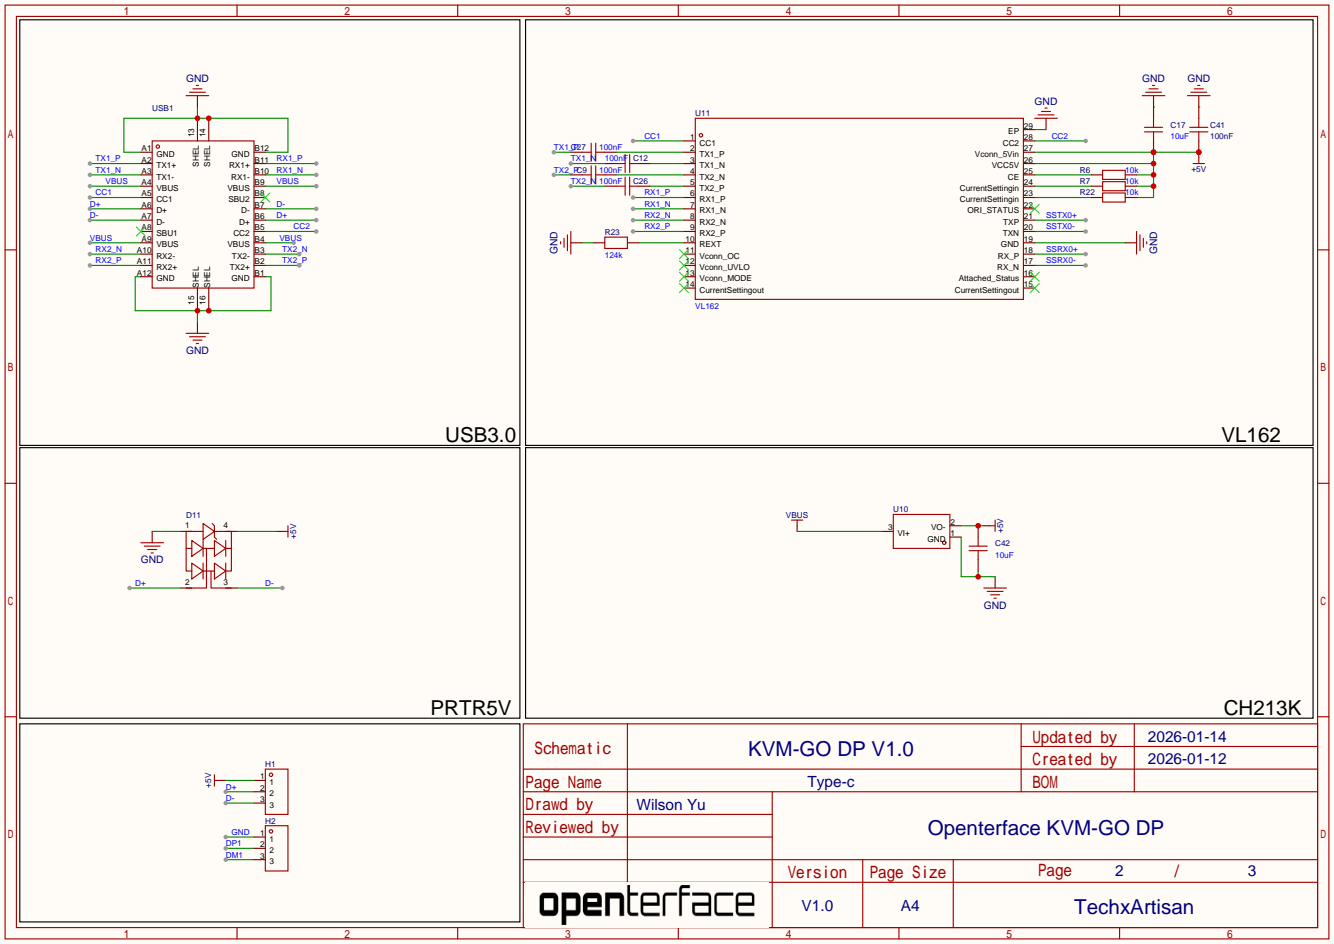
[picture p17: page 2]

Openterface KVM-GO DP

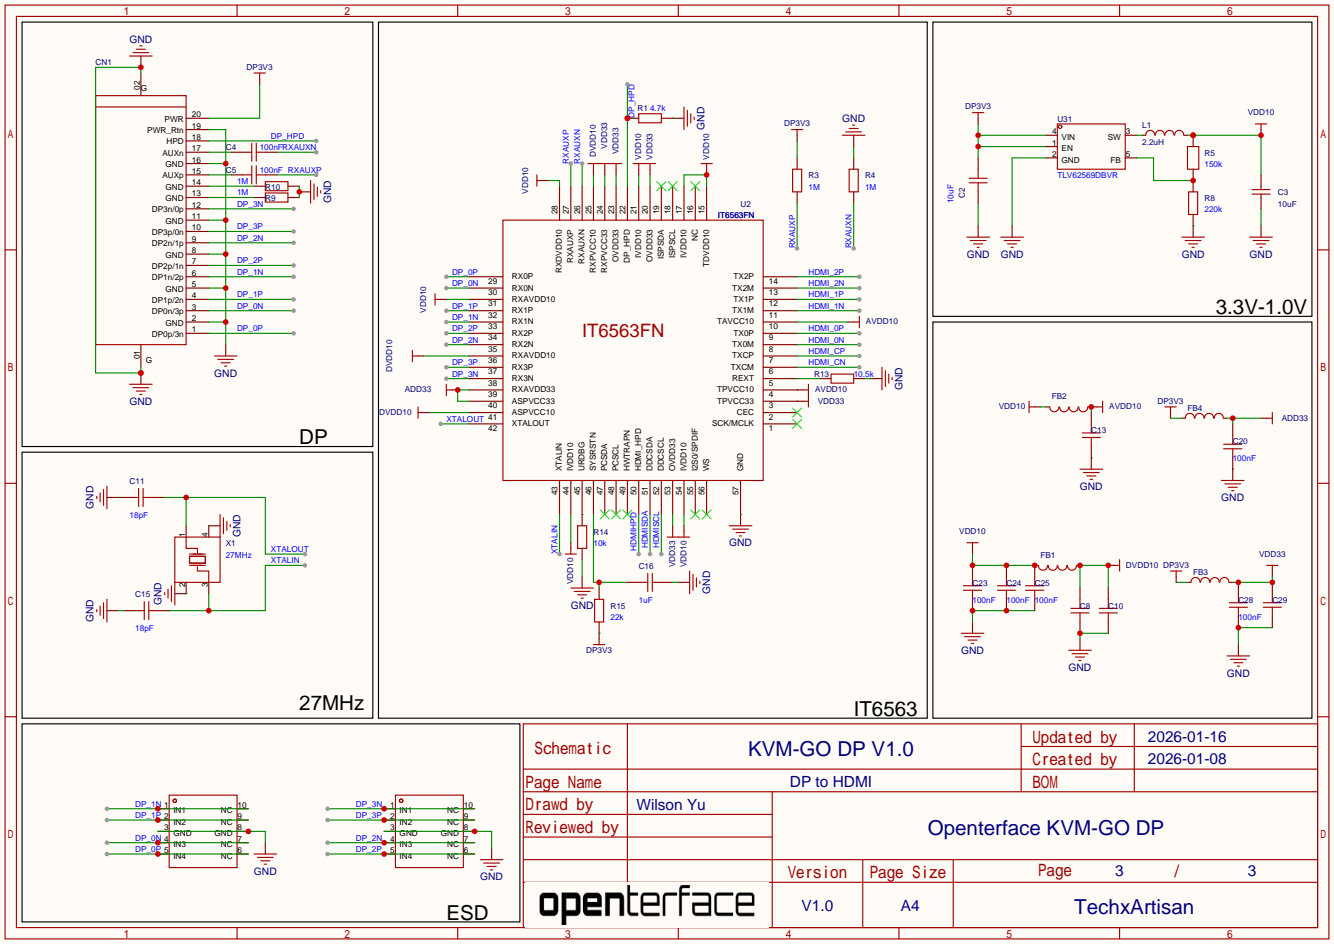
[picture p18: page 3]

Openterface KVM-GO DP

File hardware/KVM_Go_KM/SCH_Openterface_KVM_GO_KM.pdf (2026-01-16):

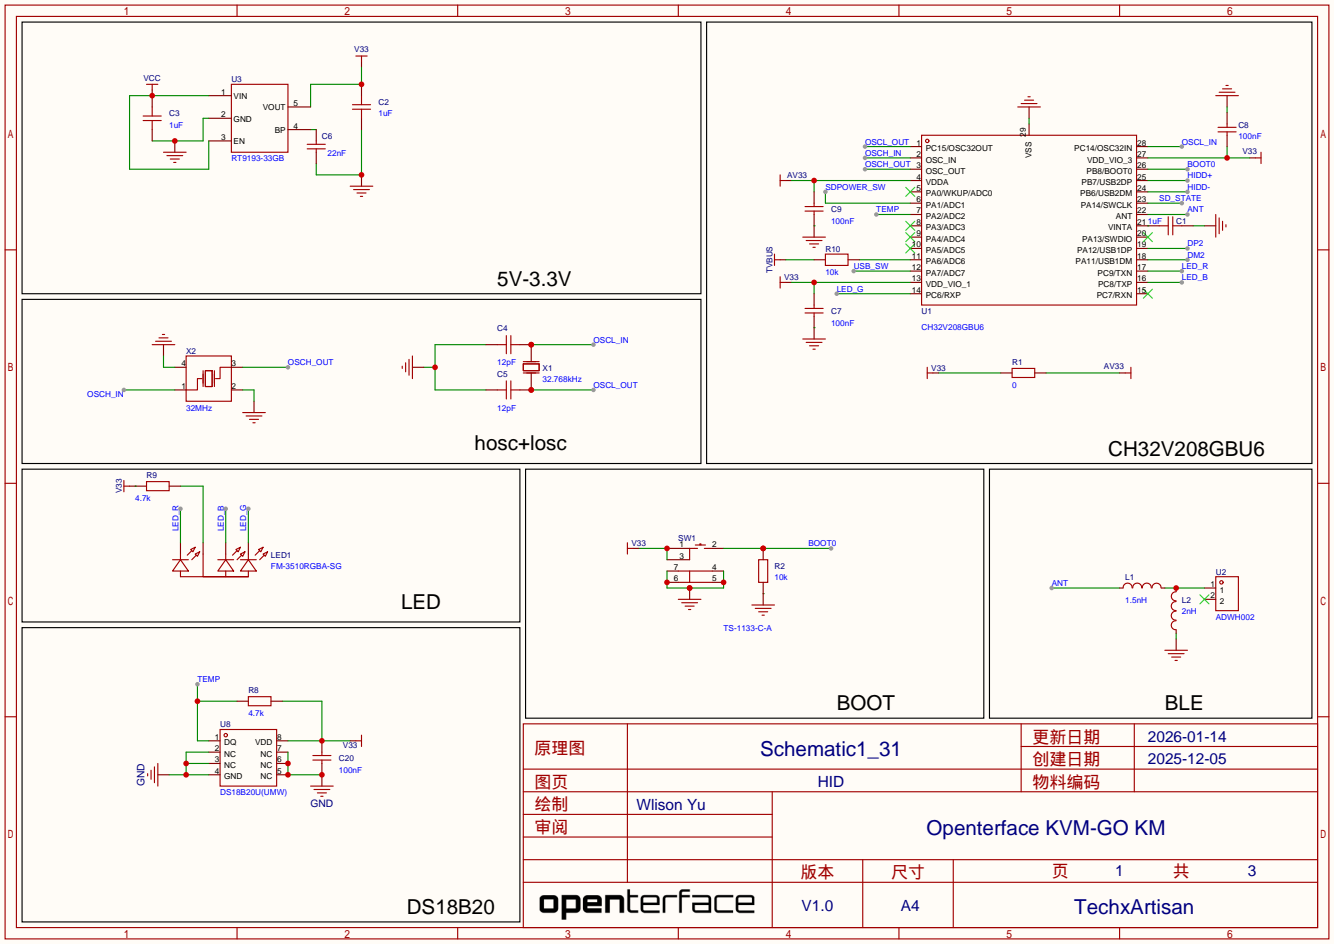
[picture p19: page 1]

Openterface KVM-GO KM

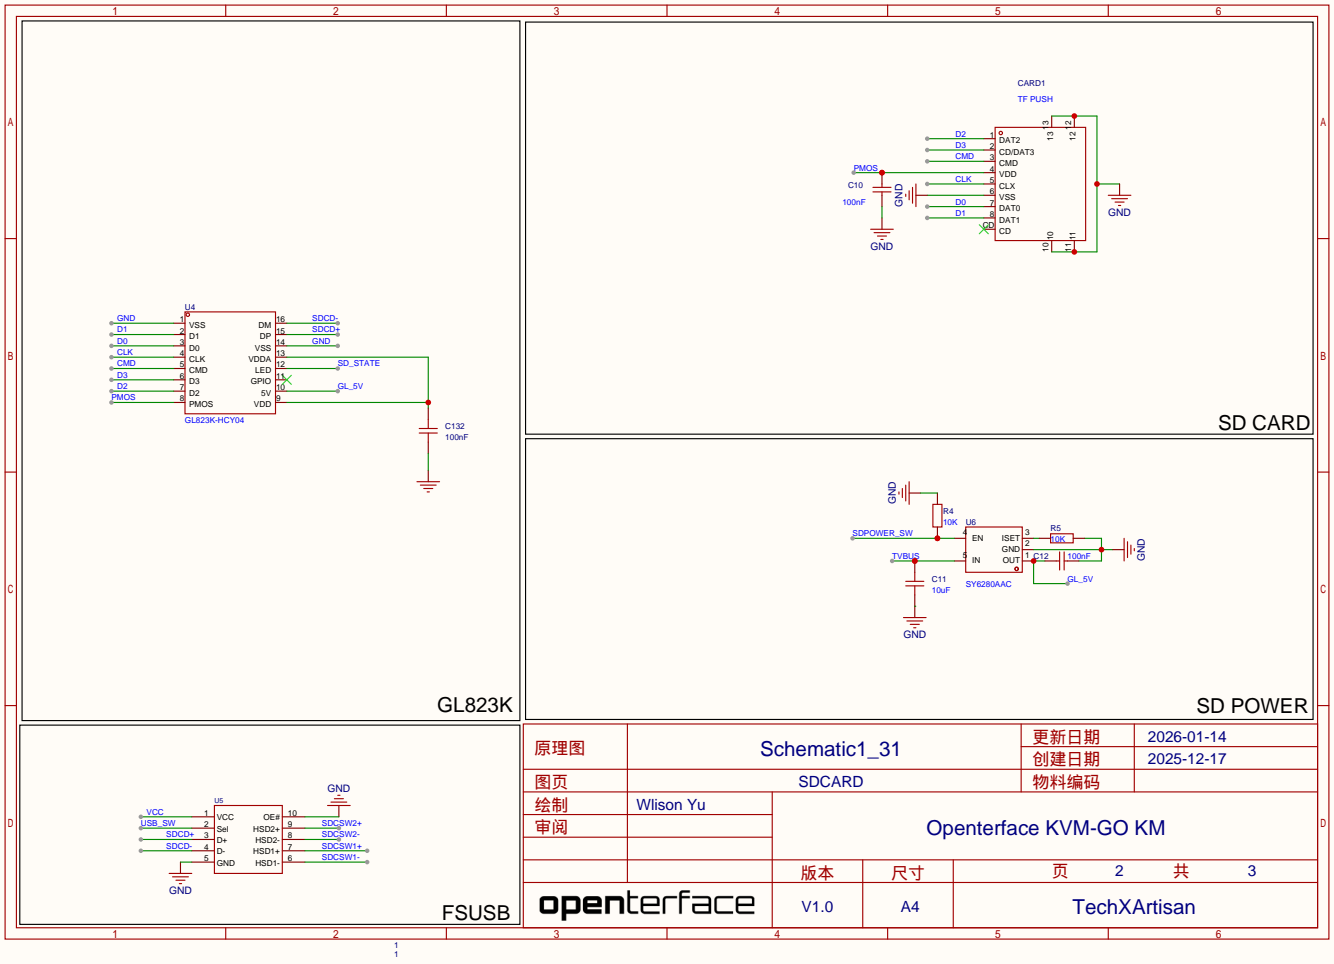
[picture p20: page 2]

SDCD-
5V 10 GPIO 11 LED 12 VDDA 13 VSS 14 DP 15 DM 16

Openterface KVM-GO KM

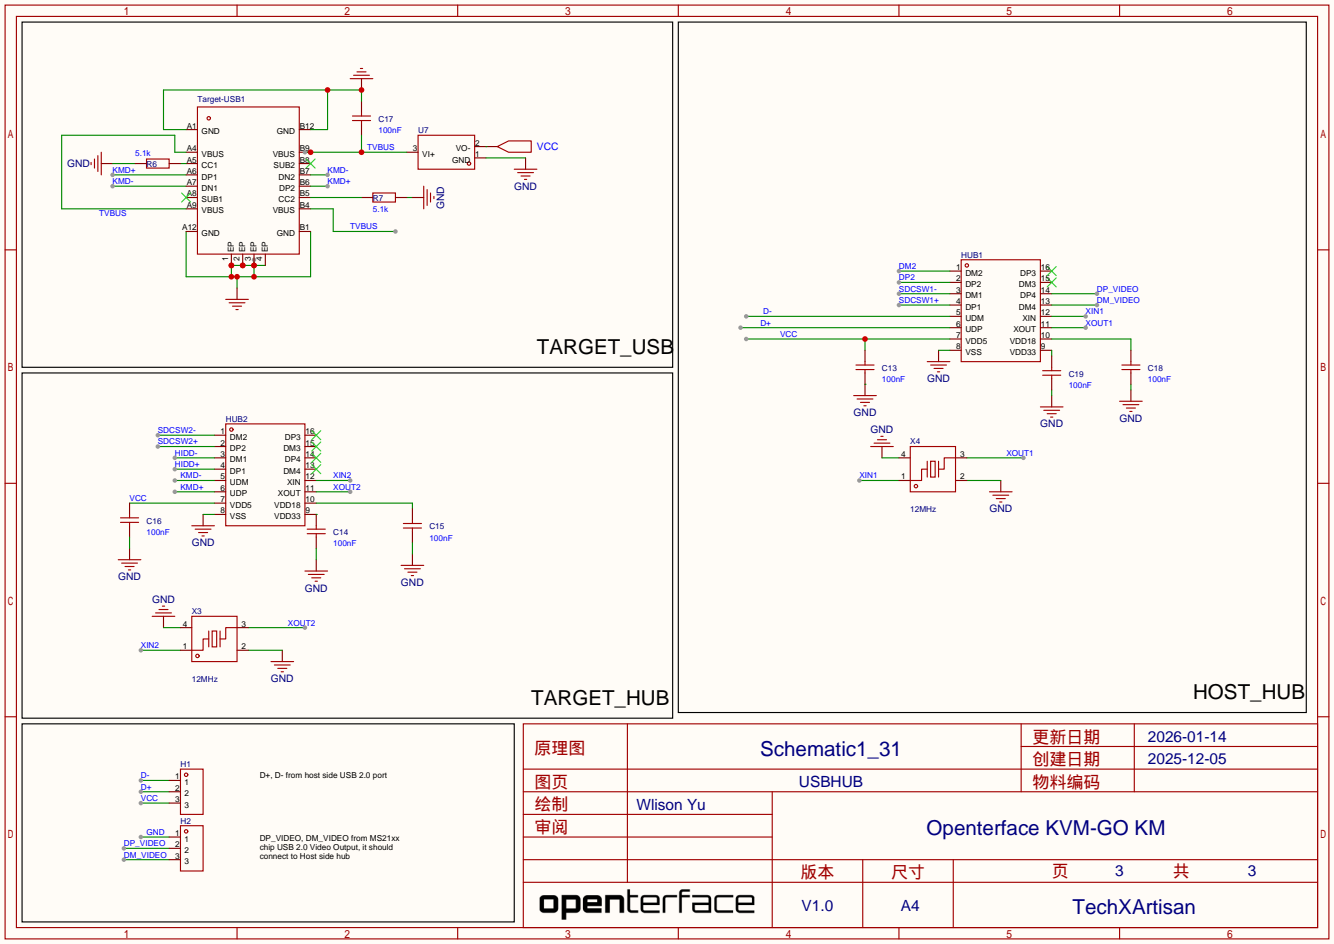
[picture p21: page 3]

D+, D- from host side USB 2.0 port

Openterface KVM-GO KM

DP_VIDEO, DM_VIDEO from MS21xx
chip USB 2.0 Video Output, it should
connect to Host side hub

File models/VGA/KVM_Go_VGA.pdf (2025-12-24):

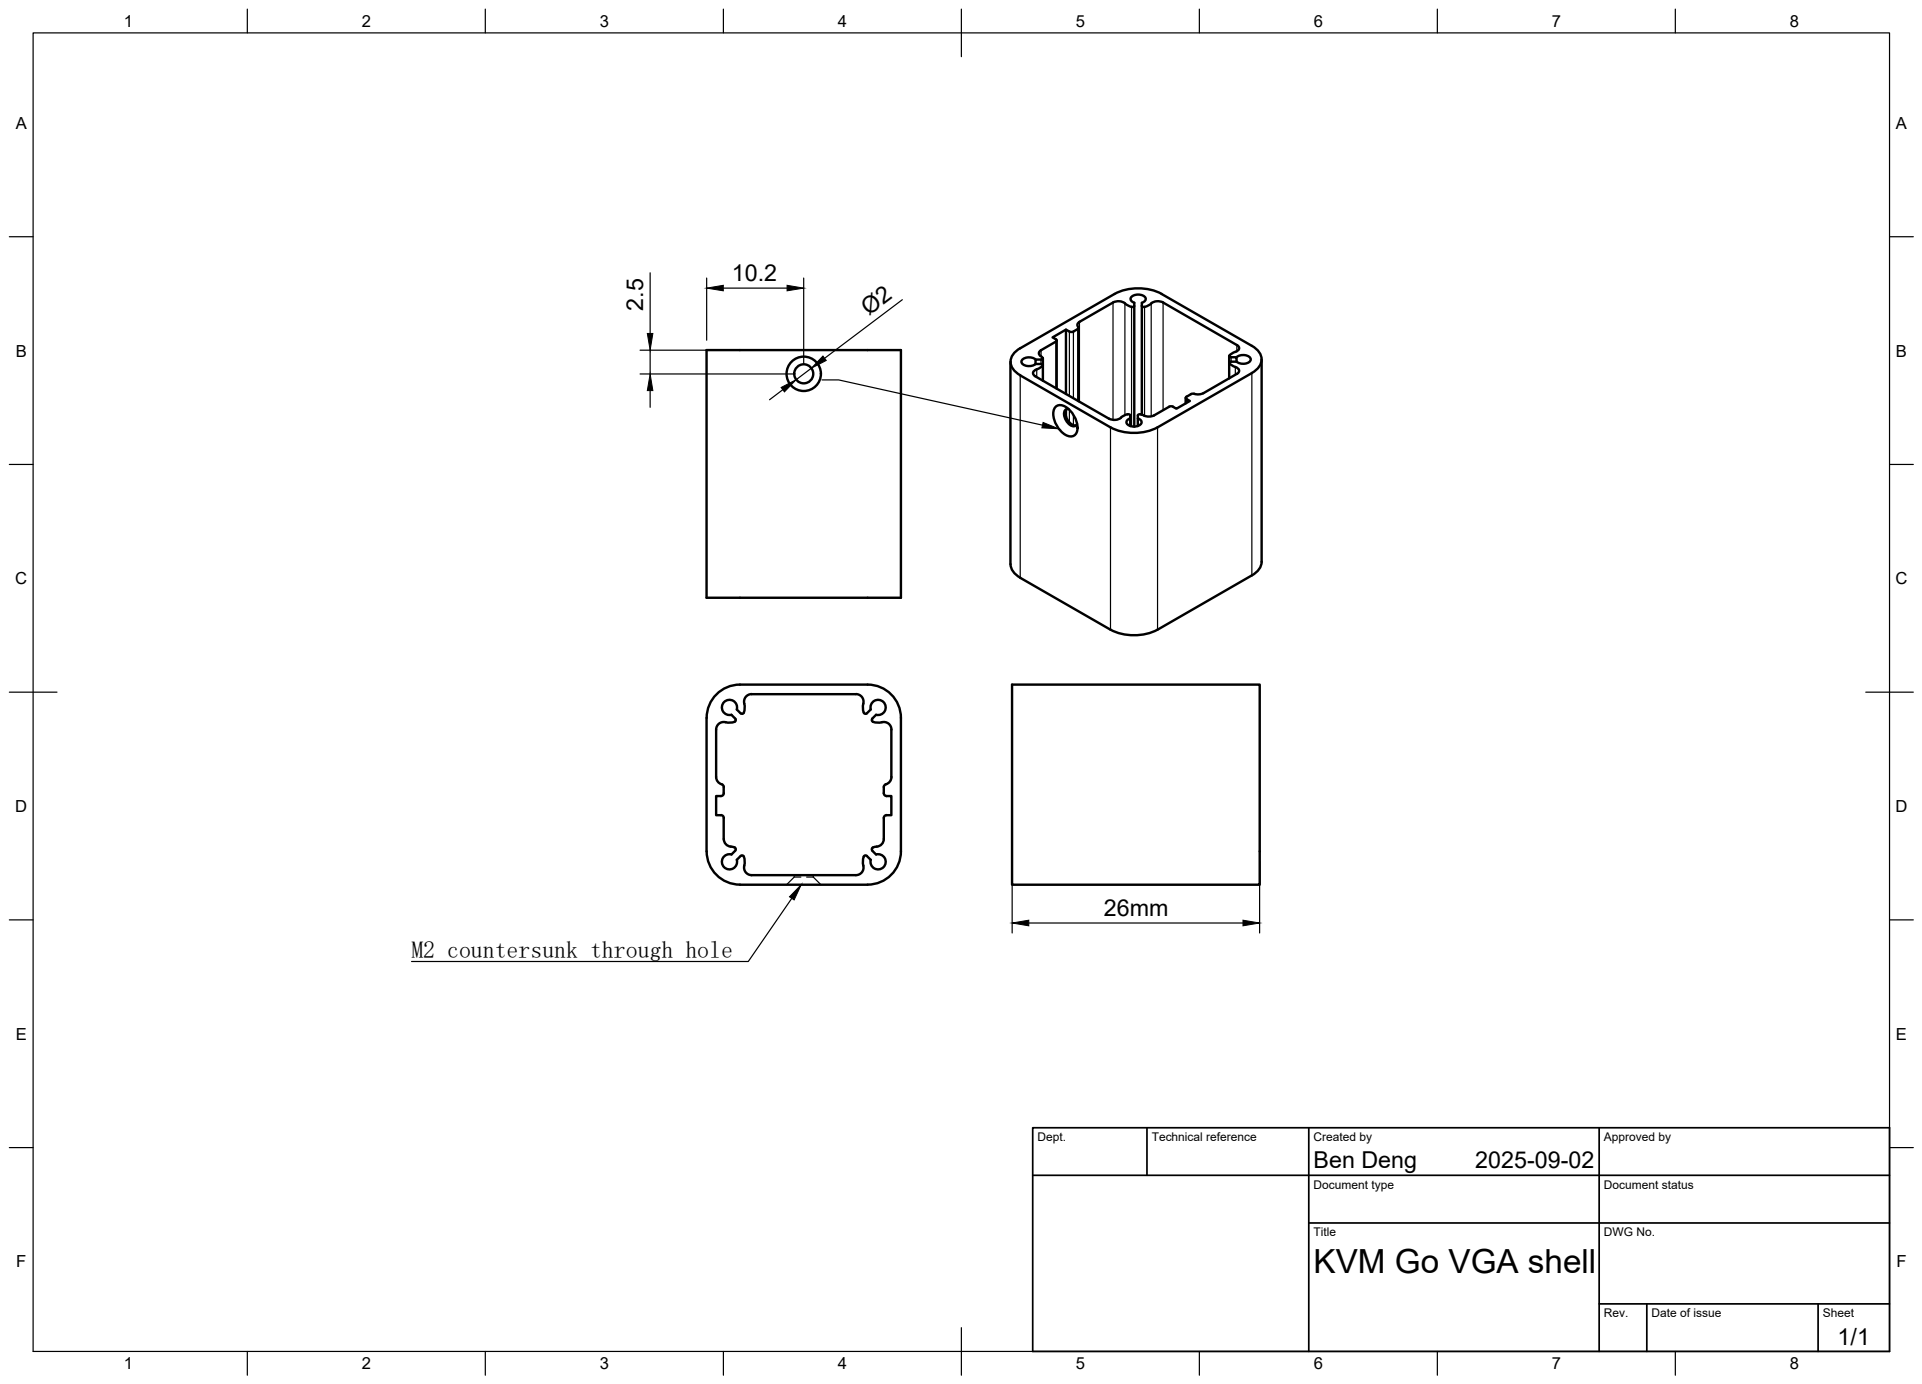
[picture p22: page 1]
Title; DWG No.; Rev.; Date of issue; Sheet

M2 countersunk through hole

Dept. | Technical reference | Created by Ben Deng 2025-09-02 | Approved by

Document type | Document status

KVM Go VGA shell

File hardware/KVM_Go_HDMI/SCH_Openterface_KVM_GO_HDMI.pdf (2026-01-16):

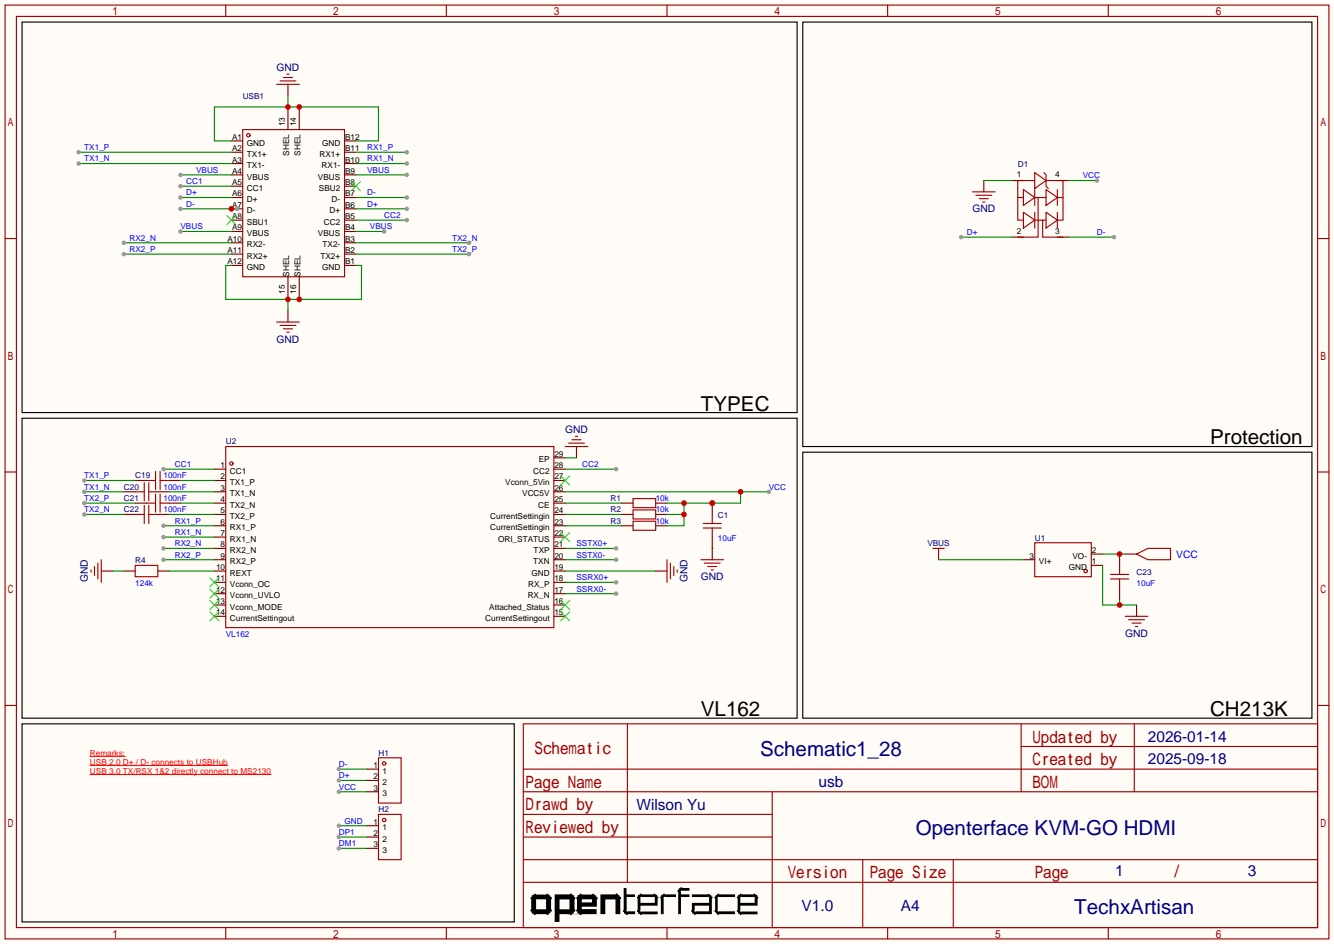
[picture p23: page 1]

Remarks:
USB 2.0 D+ / D- connects to USBHub
USB 3.0 TX/RSX 1&2 directly connect to MS2130

Openterface KVM-GO HDMI

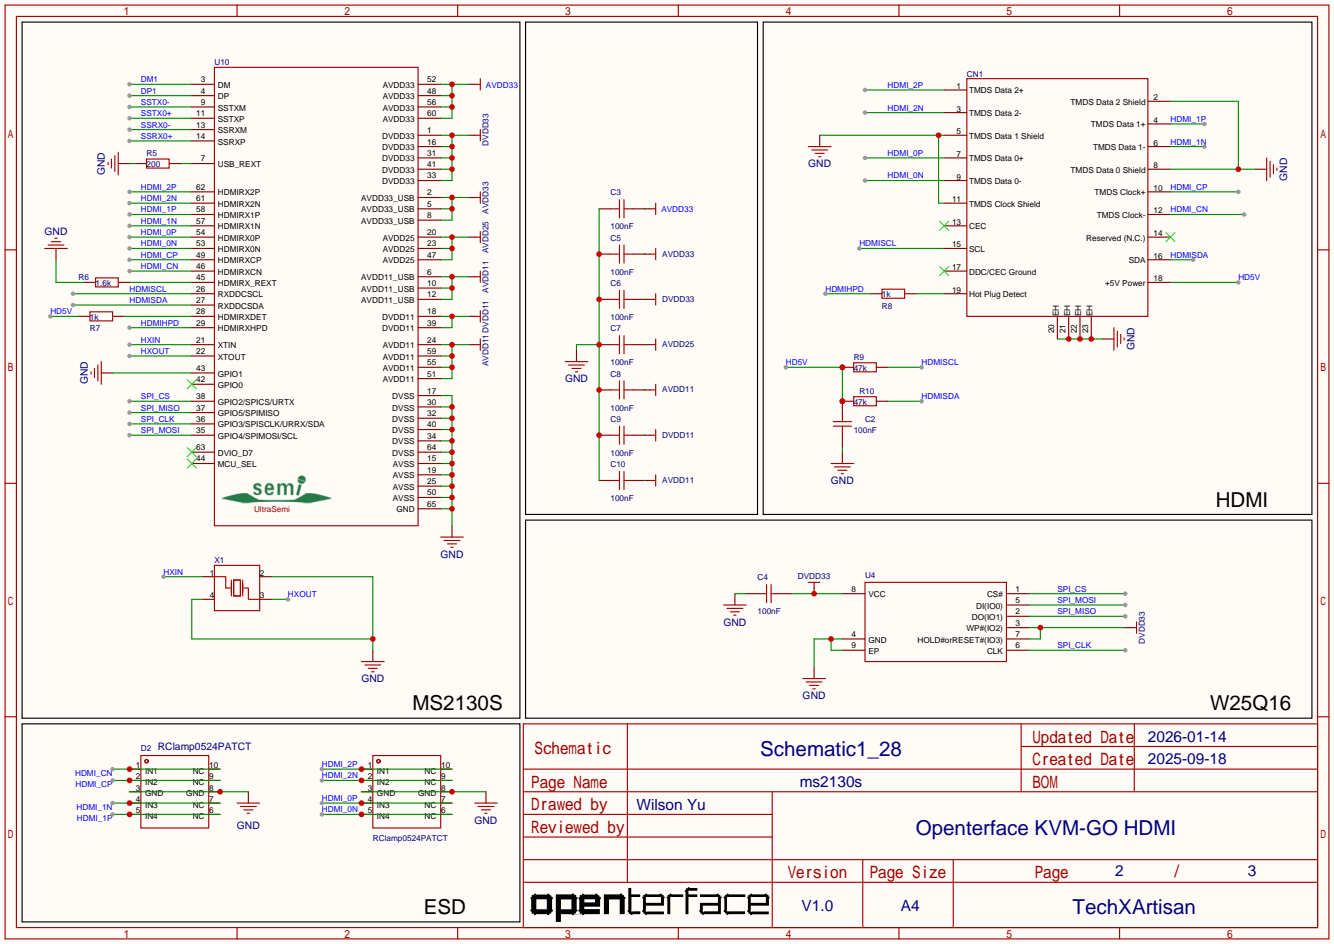
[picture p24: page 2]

HDMIRXHPD 29 HDMIRXDET 28 RXDDCSDA 27 RXDDCSCL 26

Openterface KVM-GO HDMI

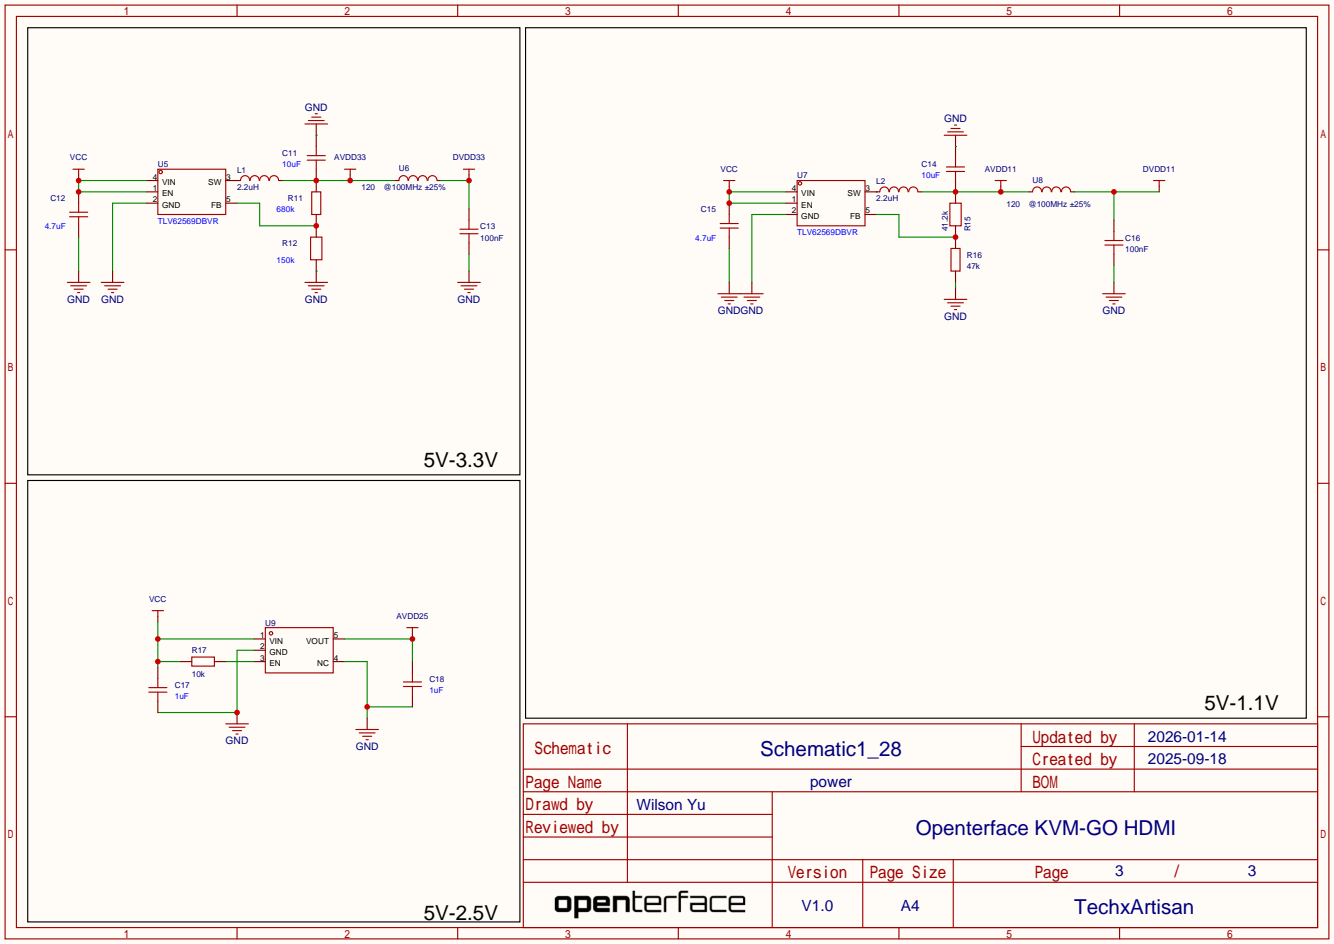
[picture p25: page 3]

Openterface KVM-GO HDMI

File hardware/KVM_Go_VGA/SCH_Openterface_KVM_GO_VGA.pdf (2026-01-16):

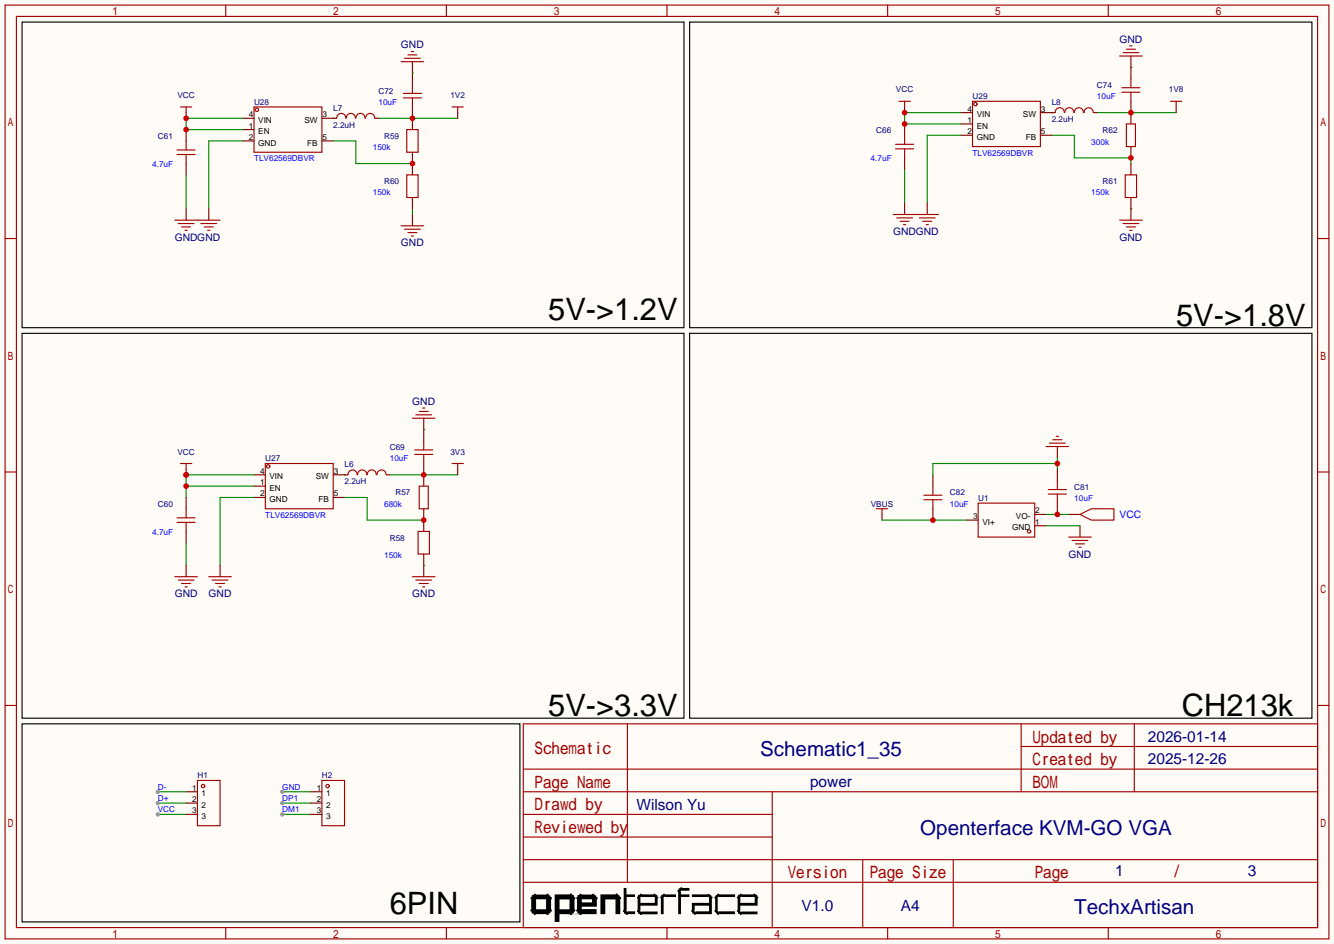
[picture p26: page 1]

Openterface KVM-GO VGA


Openterface KVM-GO VGA


Openterface KVM-GO VGA

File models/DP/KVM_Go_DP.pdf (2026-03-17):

Title; DWG No.; Rev.; Date of issue; Sheet

Dept. | Technical reference | Created by Ben Deng 2026-03-04 | Approved by

Document type | Document status

KVM Go DP shell

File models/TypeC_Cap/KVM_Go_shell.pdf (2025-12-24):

Title; DWG No.; Rev.; Date of issue; Sheet; Ben Deng 21

Dept. | Technical reference | Created by 2025-12-24 | Approved by

Document type | Document status

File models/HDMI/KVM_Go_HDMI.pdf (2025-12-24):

Title; DWG No.; Rev.; Date of issue; Sheet

Dept. | Technical reference | Created by Ben Deng 2025-12-02 | Approved by

Document type | Document status

KVM Go HDMI shell

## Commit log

2025-10-28 add models/HDMICaps_WithSDCardSlot.stl
    [HDMICaps_WithSDCardSlot.stl]
2025-11-01 add HDMI Cap and TypeC Cap
    [HDMI_Cap.stl, typec_cap.stl]
2025-11-20 KVM Go Series Protective Cover
    HDMI、DP and VGA.
    [KVM_Go_DPCaps_WithSDCardSlot and key hole.stl, KVM_Go_DPCaps_WithSDCardSlot.stl, KVM_Go_HDMICaps_WithSDCardSlot and key hole.stl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]
2025-12-24 HDMI、DP and VGA aluminum_shell
    [DP_aluminum_shell.stl, HDM_aluminum_shell.stl, VGA_aluminum_shell.stl]
2025-12-24 KVMGo series shell models
    KVM GoHDMI, DP and VGA enclosure models and dimensions.
2025-12-24 Rename models/KVM_Go_DPCaps_WithSDCardSlot and key hole.stl to models/DP/KVM_Go_DPCaps_WithSDCardSlot and key hole.stl
    [KVM_Go_DPCaps_WithSDCardSlot and key hole.stl]
2025-12-24 Rename models/KVM_Go_HDMICaps_WithSDCardSlot and key hole.stl to models/HDMI/KVM_Go_HDMICaps_WithSDCardSlot and key hole.stl
    [KVM_Go_HDMICaps_WithSDCardSlot and key hole.stl]
2025-12-24 Rename models/KVM_Go_VGACaps_WithSDCardSlot and key hole.stl to models/VGA/KVM_Go_VGACaps_WithSDCardSlot and key hole.stl
    [KVM_Go_VGACaps_WithSDCardSlot and key hole.stl]
2026-01-16 KVM-Go Schematic diagram
2026-03-11 Enhance README with PCB design and images
    Added PCB design section and updated images in README.
2026-03-12 Replace PCB design image in README
    Updated PCB design image in the README.
2026-03-16 Add KVM-GO-DP 3D model file
    [kvm_go_dp.step]
2026-03-16 Add KVM-GO-KM 3D model file
    [KVM_GO_KM.step]
2026-03-16 Add KVM-GO-VGA 3D model file
    [KVM_GO_VGA.step]
2026-03-16 Add KVM-GO-HDMI 3D model file
    [KVM_GO_HDMI.step]
2026-03-16 KVM_GO_HDMI PCB BOM and Gerber
    [KVM_GO_HDMI_BOM.xlsx, KVM_GO_HDMI_PickAndPlace.xlsx]
2026-03-16 KVM_GO_VGA BOM and Gerber
    [KVM_GO_VGA_BOM.xlsx, KVM_GO_VGA_PickAndPlace.xlsx]
2026-03-16 KVM_GO_KM BOM and Gerber
    [KVM_GO_KM_BOM.xlsx, KVM_GO_KM_PickAndPlace.xlsx]
2026-03-16 KVM_GO_DP_BOM and Gerber
    [KVM_GO_DP_BOM.xlsx, KVM_GO_DP_PickAndPlace.xlsx]
2026-03-17 KVM Go-HDMI-Assembly
2026-03-17 Rename models/KVM_Go_shell.dxf to models/TypeC_Cap /KVM_Go_shell.dxf
    [KVM_Go_shell.dxf]
2026-03-17 KVM_Go_shell CAD
    [KVM_Go_shell.dxf]
